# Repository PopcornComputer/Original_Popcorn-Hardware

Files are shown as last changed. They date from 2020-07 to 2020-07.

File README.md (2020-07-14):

# Original Popcorn Computer Hardware Design Files

### Important Note:
These files were put into production on July 14th, 2020 and are untested.
An upcoming production run will validate these files. This README file and repository will be updated to reflect the test results and suitability for future productions.
If results of our testing prove successful, the Original Popcorn produced from these files will be shipped to customers.

Original Popcorn Computer is designed using OrCAD 17. 
A free "lite" viewer is available at <a href="http://www.orcad.com/">www.orcad.com</a>

## License
<br />This work is licensed under a <a rel="license" href="http://creativecommons.org/licenses/by-sa/3.0/us/">Creative Commons Attribution-ShareAlike 3.0 United States License</a>.

Original Popcorn Computer is a derivative of C.H.I.P. by Next Thing Co. released under CC BY-SA 3.0.

Popcorn Computer is not affiliated with Next Thing Co.

Popcorn Computer is a trademark of Source Parts Inc.

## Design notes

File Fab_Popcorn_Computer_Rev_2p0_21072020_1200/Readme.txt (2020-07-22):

Board name	: POPCORN COMPUTER
Rev		: 2

Board Technology information:

No. of Layers		- EIGHT(8)

Board Size 		- 41mm x 60.5mm

Track/Spacing		- 4mil track and 4mil spacing

Via			- 16mil pad and 8mil drill
               
Component		- Mixed Technology

Gerber Format		- RS274-X

=================================================================

Note :

Please refer fab.art for stackup details.

Please confirm IPC netlist verification.

=================================================================

List of files in GERBER / arttoplotting

TOP.art		-> Gerber, Top side artwork
GND1.art	-> Gerber, Inner layer2 artwork
IN1.art		-> Gerber, Inner layer3 artwork
VCC1.art	-> Gerber, Inner layer4 artwork
GND2.art	-> Gerber, Inner layer5 artwork
IN2.art		-> Gerber, Inner layer6 artwork
VCC2.art	-> Gerber, Inner layer7 artwork
BOTTOM.art	-> Gerber, Bot side artwork
MASK_TOP.art	-> Gerber, Top side Solder Mask
MASK_BOT.art	-> Gerber, Bot side Solder Mask
SILK_TOP.art	-> Gerber, Top side Silkscreen
SILK_BOT.art	-> Gerber, Bot side Silkscreen

List of files in DRILL/ NC Drill

nc_tools_auto.txt		-> NC drill tool bit information
Popcorn Computer Rev 2p0_Release-1-8.drl	-> NC Drill file in excellon format
fab.art		   		-> Gerber, Fab drawing

Popcorn Computer Rev 2p0_Release.pdf -> File for visual compliance

Popcorn Computer Rev 2p0_Release.IPC -> IPC-D-356 netlist

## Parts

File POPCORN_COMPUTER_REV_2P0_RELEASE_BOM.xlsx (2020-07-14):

Popcorn Computer Rev. 2.0 Revised: Monday, July 13, 2020
Revision: 2.0
Copyright: Source Parts Inc.
Bill Of Materials July 14,2020 13:23:38 | Page1
Item | Quantity | Reference | Part | Package
______________________________________________
1 | 1 | ANT1 | NC-ANT | WIFI-ANT-SD73412-011H1_3A
2 | 1 | ANT2 | ANT | WIFI-1206
3 | 2 | C1,C5 | 18pF-1% | C0201
4 | 21 | C2,C7,C8,C13,C14,C16,C17,C18,C19,C21,C32,C45,C85,C149,C157,C167,C177,C178,C16043,C16060,C16062 | 10uF | C0603
5 | 3 | C3,C532,C533 | 0.1uF | C0603
6 | 4 | C4,C16052,C16053,C16054 | 220pF | C0603
7 | 24 | C9,C22,C24,C26,C37,C49,C150,C153,C154,C158,C159,C160,C161,C164,C179,C180,C181,C182,C183,C184,C185,C186,C296,C299 | 1uF | C0402
8 | 14 | C10,C11,C12,C25,C27,C28,C29,C50,C66,C68,C70,C71,C74,C76 | 4.7uF | C0603
9 | 1 | C15 | 102 | C0402
10 | 6 | C20,C165,C173,C174,C175,C176 | 102 | C0201
11 | 34 | C33,C34,C35,C36,C54,C69,C72,C81,C82,C83,C84,C90,C91,C92,C93,C94,C95,C96,C102,C103,C104,C105,C106,C148,C151,C152,C166,C168,C170,C172,C189,C295,C297,C298 | 104 | C0201
12 | 1 | C41 | 0.1uF | C0201
13 | 7 | C47,R50,C52,C60,C109,C530,C531 | NC | C0201
14 | 1 | C51 | 1.0pF | C0201
15 | 1 | C53 | 22pF | C0201
16 | 1 | C55 | 271 | C0201
17 | 1 | C56 | 331 | C0201
18 | 2 | C67,C73 | 47pF | C0201
19 | 9 | C78,C79,C527,C528,C16037,C16041,C16042,C16055,C16056 | 22uF | C0805
20 | 2 | C142,C169 | 4.7uF | C0402
21 | 1 | C188 | 4.7u/6.3V | C0603
22 | 4 | C220,C221,C223,C224 | 104 | C0402
23 | 1 | C222 | NC/104 | C0402
24 | 1 | C294 | 100pF | C0201
25 | 6 | C496,C497,C498,C499,C510,C514 | 0.1uF/10V | C0402
26 | 2 | C512,C513 | 4.7uF/10V | C0603
27 | 5 | C524,C526,C16071,C16072,C16073 | 0.1uf | C0402
28 | 1 | C525 | 10uf | C0805
29 | 1 | C529 | 75Pf | C0402
30 | 1 | C16038 | 100uF / 10V | C1210
31 | 1 | C16039 | 1uf | C0201
32 | 1 | C16040 | 22uF/10V | C0805
33 | 2 | C16057,C16058 | 1uF | C0603
34 | 2 | C16059,C16061 | 0.1uF/50V | C0603
35 | 4 | C16067,C16068,C16069,C16070 | 10NF/35V | C0402
36 | 1 | D1 | PWR | D0603
37 | 1 | D2 | STAT | D0603
38 | 1 | D18 | BAT54S | SOT-23
39 | 1 | D21 | LED | D0603
40 | 1 | ESD38 | NC/AU0511P1 | R0402
41 | 2 | J2,J1202 | USB Type-C | DX07B024JJ1R1500
42 | 1 | J3 | BATTERY | CON2-PT2-6X6H4_7B
43 | 1 | J4 | HEADER 2 | hdr_2x1
44 | 1 | J1204 | USB-MACRO-SOCKET | usb-mic-a01sb141bh2_4a
45 | 5 | L2,L3,L4,L5,L6 | 2.2uH-DCR<0.1R-1.5A/ELL4LG2R2NA | L3518
46 | 1 | L9 | 1.8uH | L0603
47 | 1 | L10 | 12UH | ASPI-6045S-120M-T
48 | 1 | L9003 | SLW4012P1R5MST | SLW4012P1R5MST
49 | 1 | L9004 | 180nH | L0603
50 | 1 | Q4 | MMBT3904 | SOT-23
51 | 1 | Q11 | BSN20 | SOT-23
52 | 10 | RN20,RN21,RN22,RN23,RN24,RN25,RN26,RN27,RN28,RN29 | 33R*4 | YC124-FR-0724RL
53 | 1 | RN30 | 24R*4 | YC124-FR-0724RL
54 | 2 | RN31,RN32 | 10k | YC124-JR-0710KL
55 | 2 | R1,R4 | 4.7K | C0201
56 | 5 | R2,R3,R6,R18,R103 | 2K2 | C0201
57 | 1 | R7 | 0R03 | R0805
58 | 4 | R8,R83,R102,R113 | 1K | C0201
59 | 1 | R9 | 1R | R0402
60 | 5 | R10,R11,R55,R56,R206 | 10K | C0201
61 | 2 | R12,R122 | 0R | C0201
62 | 2 | R13,R121 | 200K-1% | C0201
63 | 2 | R14,R78 | 100K-1% | C0201
64 | 1 | R15 | 150K-1% | C0201
65 | 2 | R16,R17 | 47K | C0201
66 | 1 | R20 | 2K | C0201
67 | 1 | R45 | 1.2pF | C0201
68 | 5 | R48,R49,R51,R52,R53 | 33K | C0201
69 | 2 | R58,R59 | NC-10K | C0201
70 | 1 | R60 | 75R | C0201
71 | 1 | R61 | NC-0R | C0201
72 | 2 | R62,R63 | NC/0R | C0201
73 | 6 | R65,R66,R105,R909,R1001,R1002 | 100K | C0201
74 | 6 | R68,R100,R101,R420,R421,R422 | 24R | C0201
75 | 2 | R71,R94 | 240R-1% | C0201
76 | 1 | R77 | 0 | C0201
77 | 1 | R79 | 442K-1% | C0201
78 | 1 | R80 | NC-0R | R0805
79 | 1 | R81 | 0R | R0805
80 | 4 | R89,R90,R91,R416 | 2K-1% | C0201
81 | 1 | R192 | 1.5K | C0201
82 | 1 | R209 | NC/10K | R0402
83 | 1 | R888 | 22R/1% | R0402
84 | 1 | R890 | 10K | R0402
85 | 1 | R908 | 49.9 | C0201
86 | 1 | R910 | 13.3K | C0201
87 | 1 | R1000 | 470ohm | C0201
88 | 2 | R16038,R16077 | 1MOHM | R0402
89 | 1 | R16039 | 315.8kOHM | R0402
90 | 14 | R16053,R16054,R16055,R16056,R16060,R16061,R16062,R16063,R16069,R16070,R16071,R16072,R16075,R16076 | 10.0k | R0201
91 | 3 | R16057,R16058,R16074 | 100K | R0402
92 | 1 | R16064 | 23.7K | R0402
93 | 2 | R16065,R16067 | 5K | R0402
94 | 1 | R16066 | 13.7K | R0402
95 | 1 | R16068 | 51.1K | R0402
96 | 1 | R16073 | 510K | R0402
97 | 1 | R16078 | NC/0R | R0603
98 | 1 | SW1 | KEY-2PIN_0 | SW_4P_TC3061B
99 | 1 | SW2 | SW_PB_SPST | SW_4P_TC3061B
100 | 3 | TP2,TP13,TP14 | DC3-SET | TP30_SMD
101 | 1 | TP3 | LS | PAD5_5D3
102 | 1 | TP4 | VMIC | TP30_SMD
103 | 3 | TVS1,TVS2,TVS3 | TVS2200 | TVS2200
104 | 2 | T84,T85 | TP_0.7 | TP30_SMD
105 | 1 | U1 | R8 | TQFP177P0_4
106 | 1 | U3 | AXP209 | QFN49_0_4H0_8A
107 | 1 | U4 | LP3220SAB5F/SY8088 | SOT23_5H14A
108 | 1 | U8 | TS5USBA224RSWR | TS5USBA224
109 | 1 | U9 | 8723BS | QFN44-AP6476-12X12H1_6A
110 | 1 | U10 | TS3A226AEYFFR | TS3A226AE
111 | 1 | U12 | LP3220SAB5F\SY8088 | SOT23_5H14A
112 | 2 | U13,U14 | LCD_CN | CON2X20-PT2_54-5_2X31_2H2A
113 | 1 | U29 | DDR3-FBGA96 | FBGA96C80P9X13
114 | 1 | U34 | NCEMASD9-08G | NCEMASD9-08G
115 | 1 | U38 | TPS54302DDCR | sot23_6p
116 | 1 | U39 | RDSW282/XMSS1R6G0PA-001 | rfsw6b105_105h40
117 | 1 | U40 | CH340E | msop10
118 | 1 | U41 | WAS7227Q | WAS7227Q
119 | 1 | U42 | TPS65988 | slvsdb5a
120 | 2 | U46,U47 | TPD6S300 | QFN20
121 | 1 | U48 | W25X05CLSNIG | soic8
122 | 1 | U49 | TPS2069 | HVSSOP_8
123 | 1 | U50 | TPS2120 | TPS2120
124 | 1 | U9012 | SY7088 | SY7088
125 | 1 | X1 | 24M-20pF-10PPM | CRYSTAL-4P-3225-H1A

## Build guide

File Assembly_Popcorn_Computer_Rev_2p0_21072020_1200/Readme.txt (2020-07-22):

Board name	: POPCORN COMPUTER
Rev		: 2

Board Technology information:

No. of Layers		- EIGHT(8)

Board Size 		- 41mm x 60.5mm

Track/Spacing		- 4mil track and 4mil spacing

Via			- 16mil pad and 8mil drill
               
Component		- Mixed Technology

Gerber Format		- RS274-X

=================================================================

List of files in ASSY/ for Assembly
PASTE_TOP.art		-> Gerber, Top Side Solder Paste
PASTE_BOT.art		-> Gerber, Bot Side Solder Paste
ASSEMBLY_TOP.art	-> Gerber, Top Assembly Drawing
ASSEMBLY_BOT.art	-> Gerber, Bot Assembly Drawing
place_txt.txt		-> Components XY Location

Popcorn Computer Rev 2p0_Assembly.pdf -> File for visual compliance

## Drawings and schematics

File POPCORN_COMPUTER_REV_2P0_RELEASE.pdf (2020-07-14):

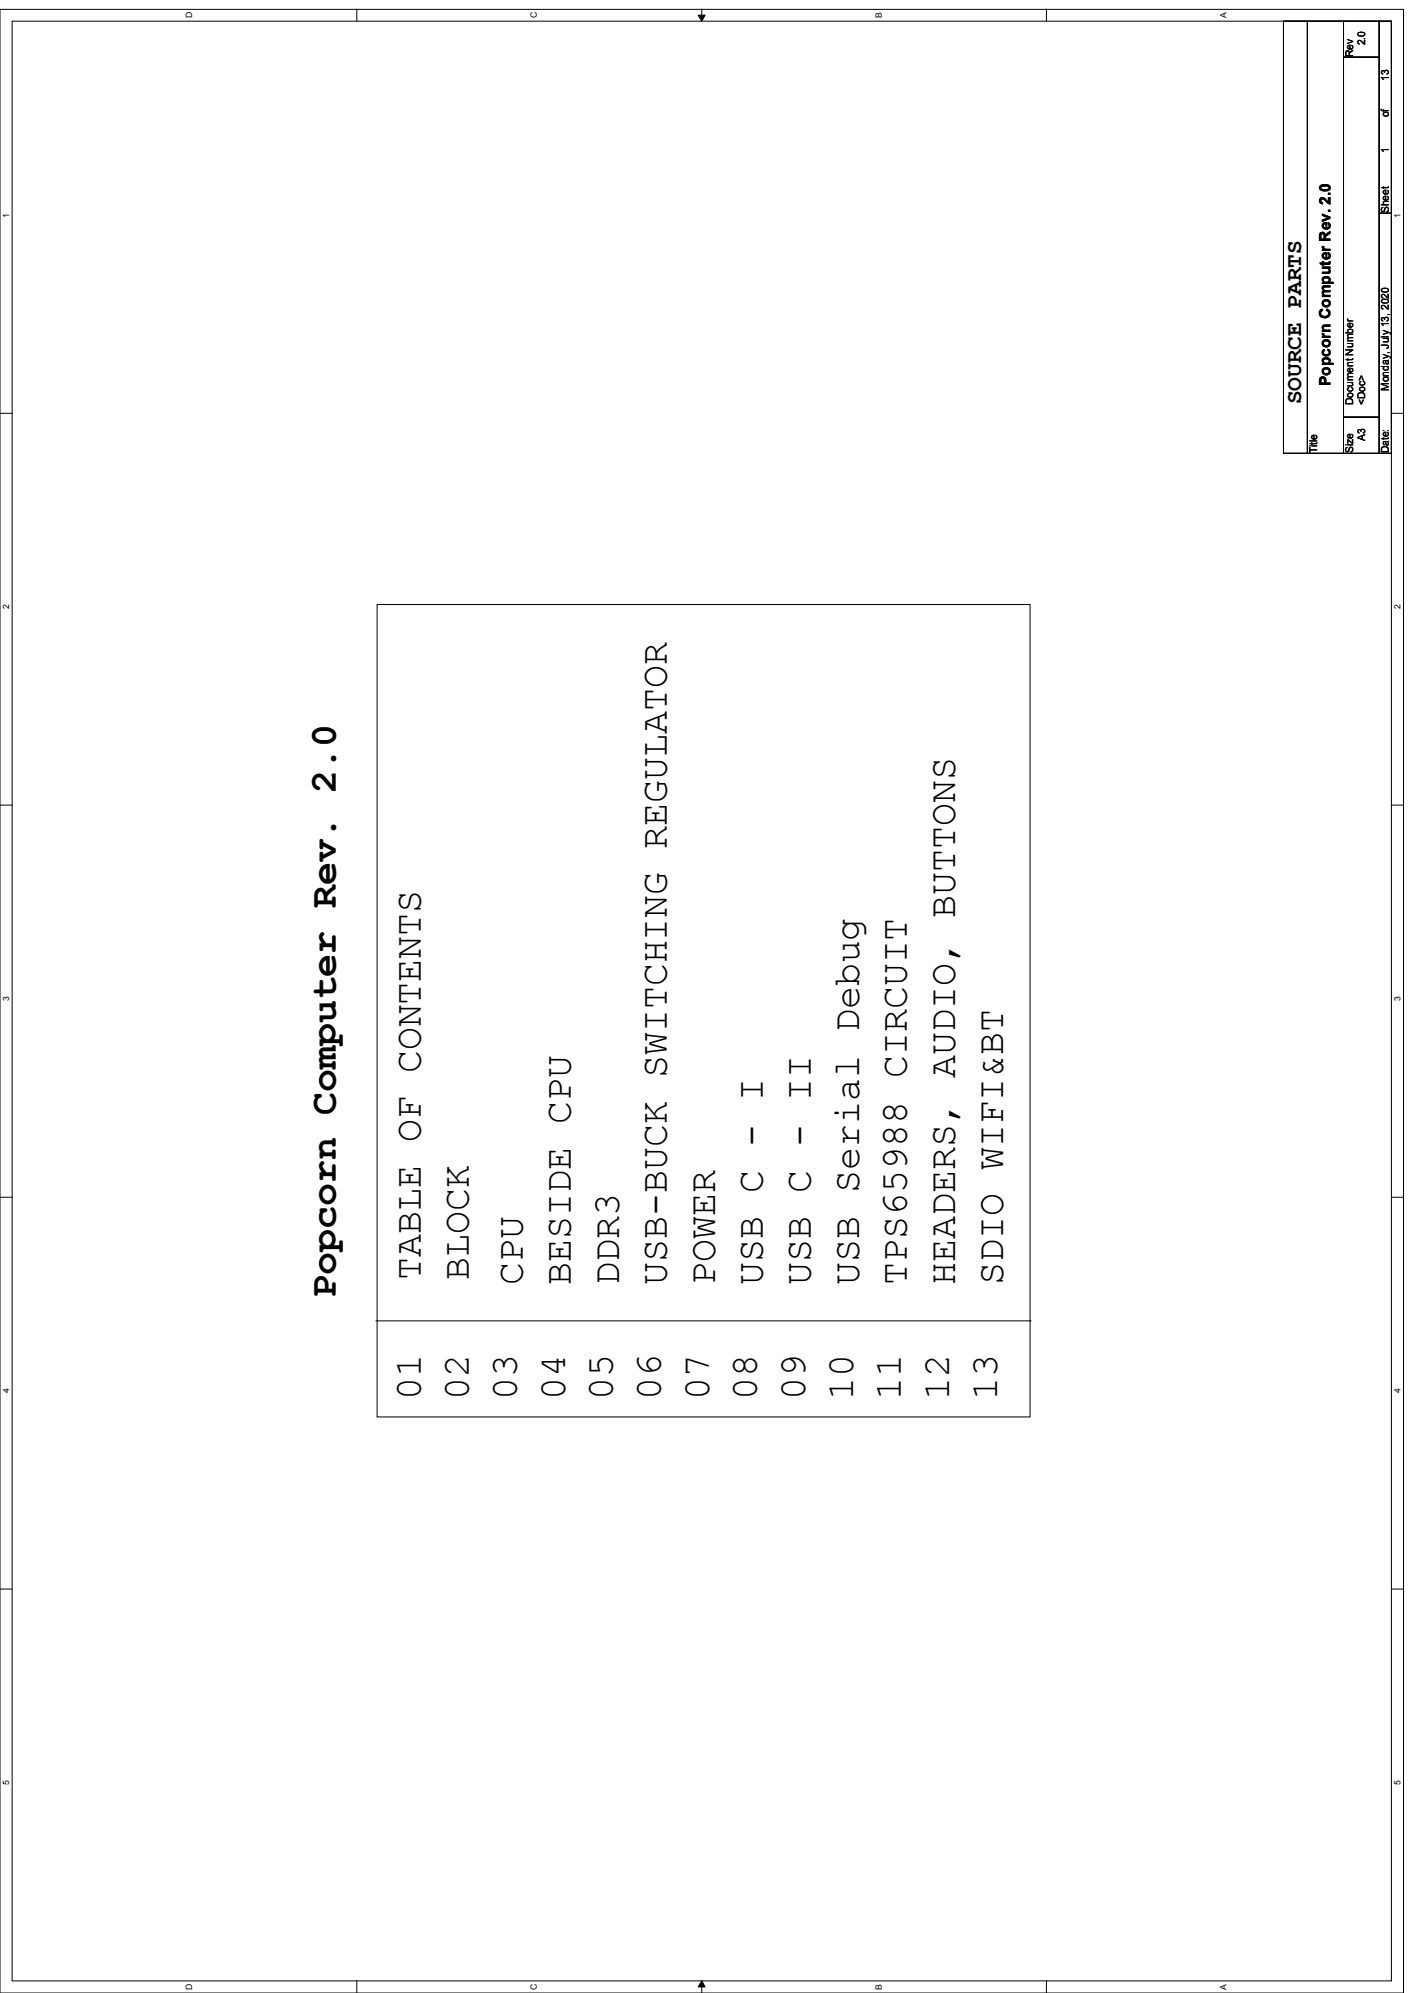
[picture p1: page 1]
SOURCE PARTS; BLOCK; CPU; BESIDE CPU; DDR3; POWER; USB C - I; USB C - II; TPS65988 CIRCUIT; Title; <Doc> 2.0; 1 13 Monday, July 13, 2020

Size Document Number Rev

Date: Sheet of

Popcorn Computer Rev. 2.0

USB-BUCK SWITCHING REGULATOR

HEADERS, AUDIO, BUTTONS

TABLE OF CONTENTS

USB Serial Debug

SDIO WIFI&BT

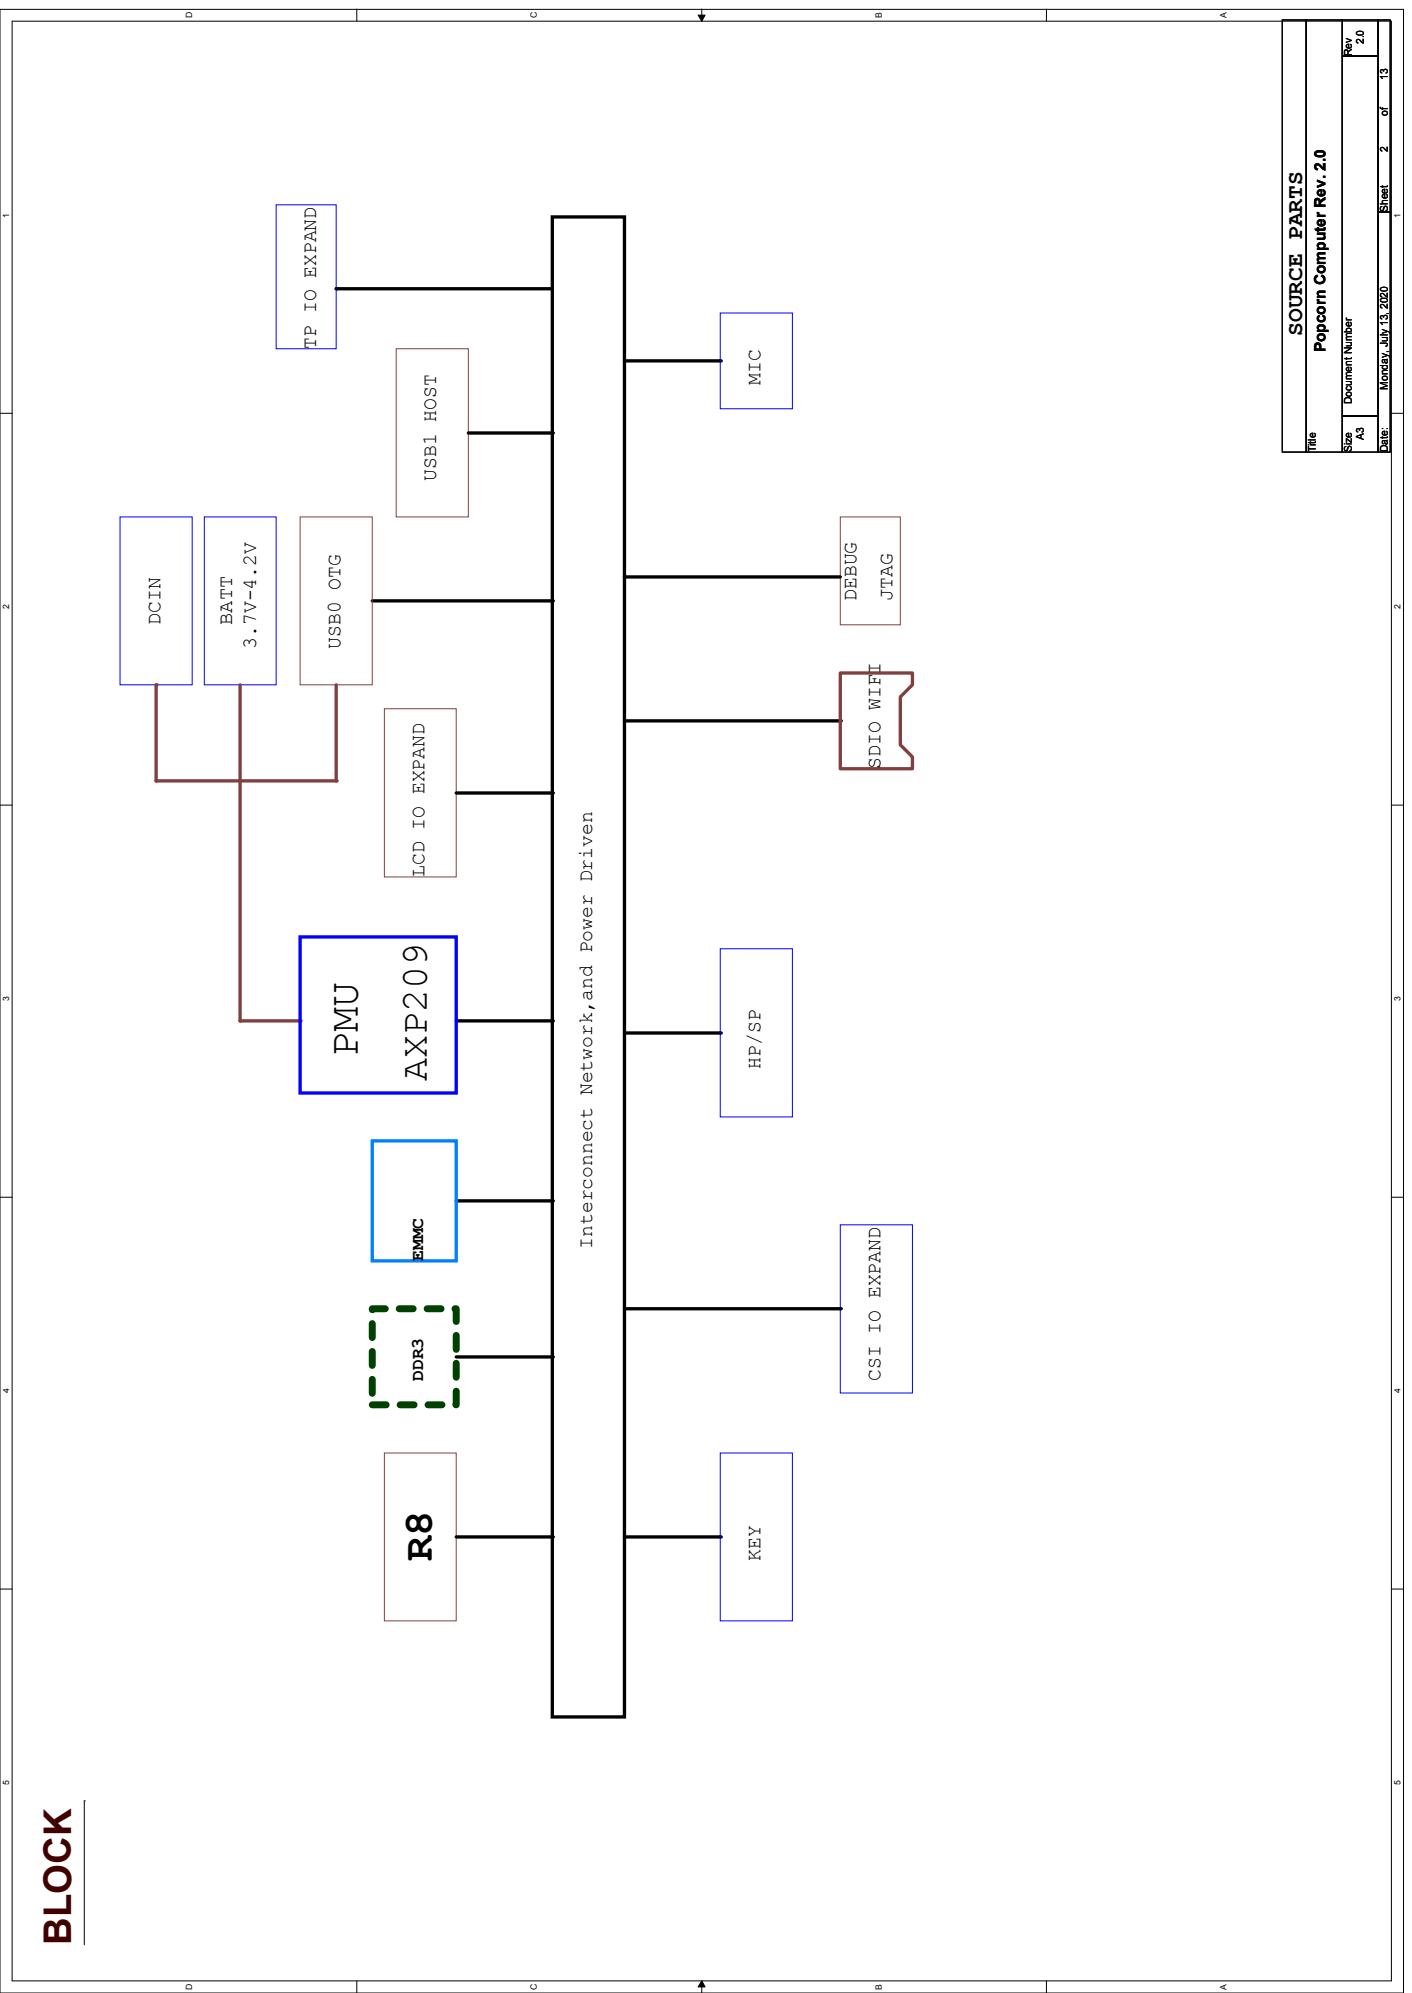
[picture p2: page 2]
SDIO WIFI; BATT; DCIN; USB0 OTG; DEBUG; JTAG; KEY; PMU; AXP209; MIC; BLOCK; EMMC; USB1 HOST; DDR3 R8; SOURCE PARTS; Title; 2 13 Monday, July 13, 2020

Size Document Number Rev

Date: Sheet of

Popcorn Computer Rev. 2.0

TP IO EXPAND

LCD IO EXPAND

Interconnect Network,and Power Driven

CSI IO EXPAND

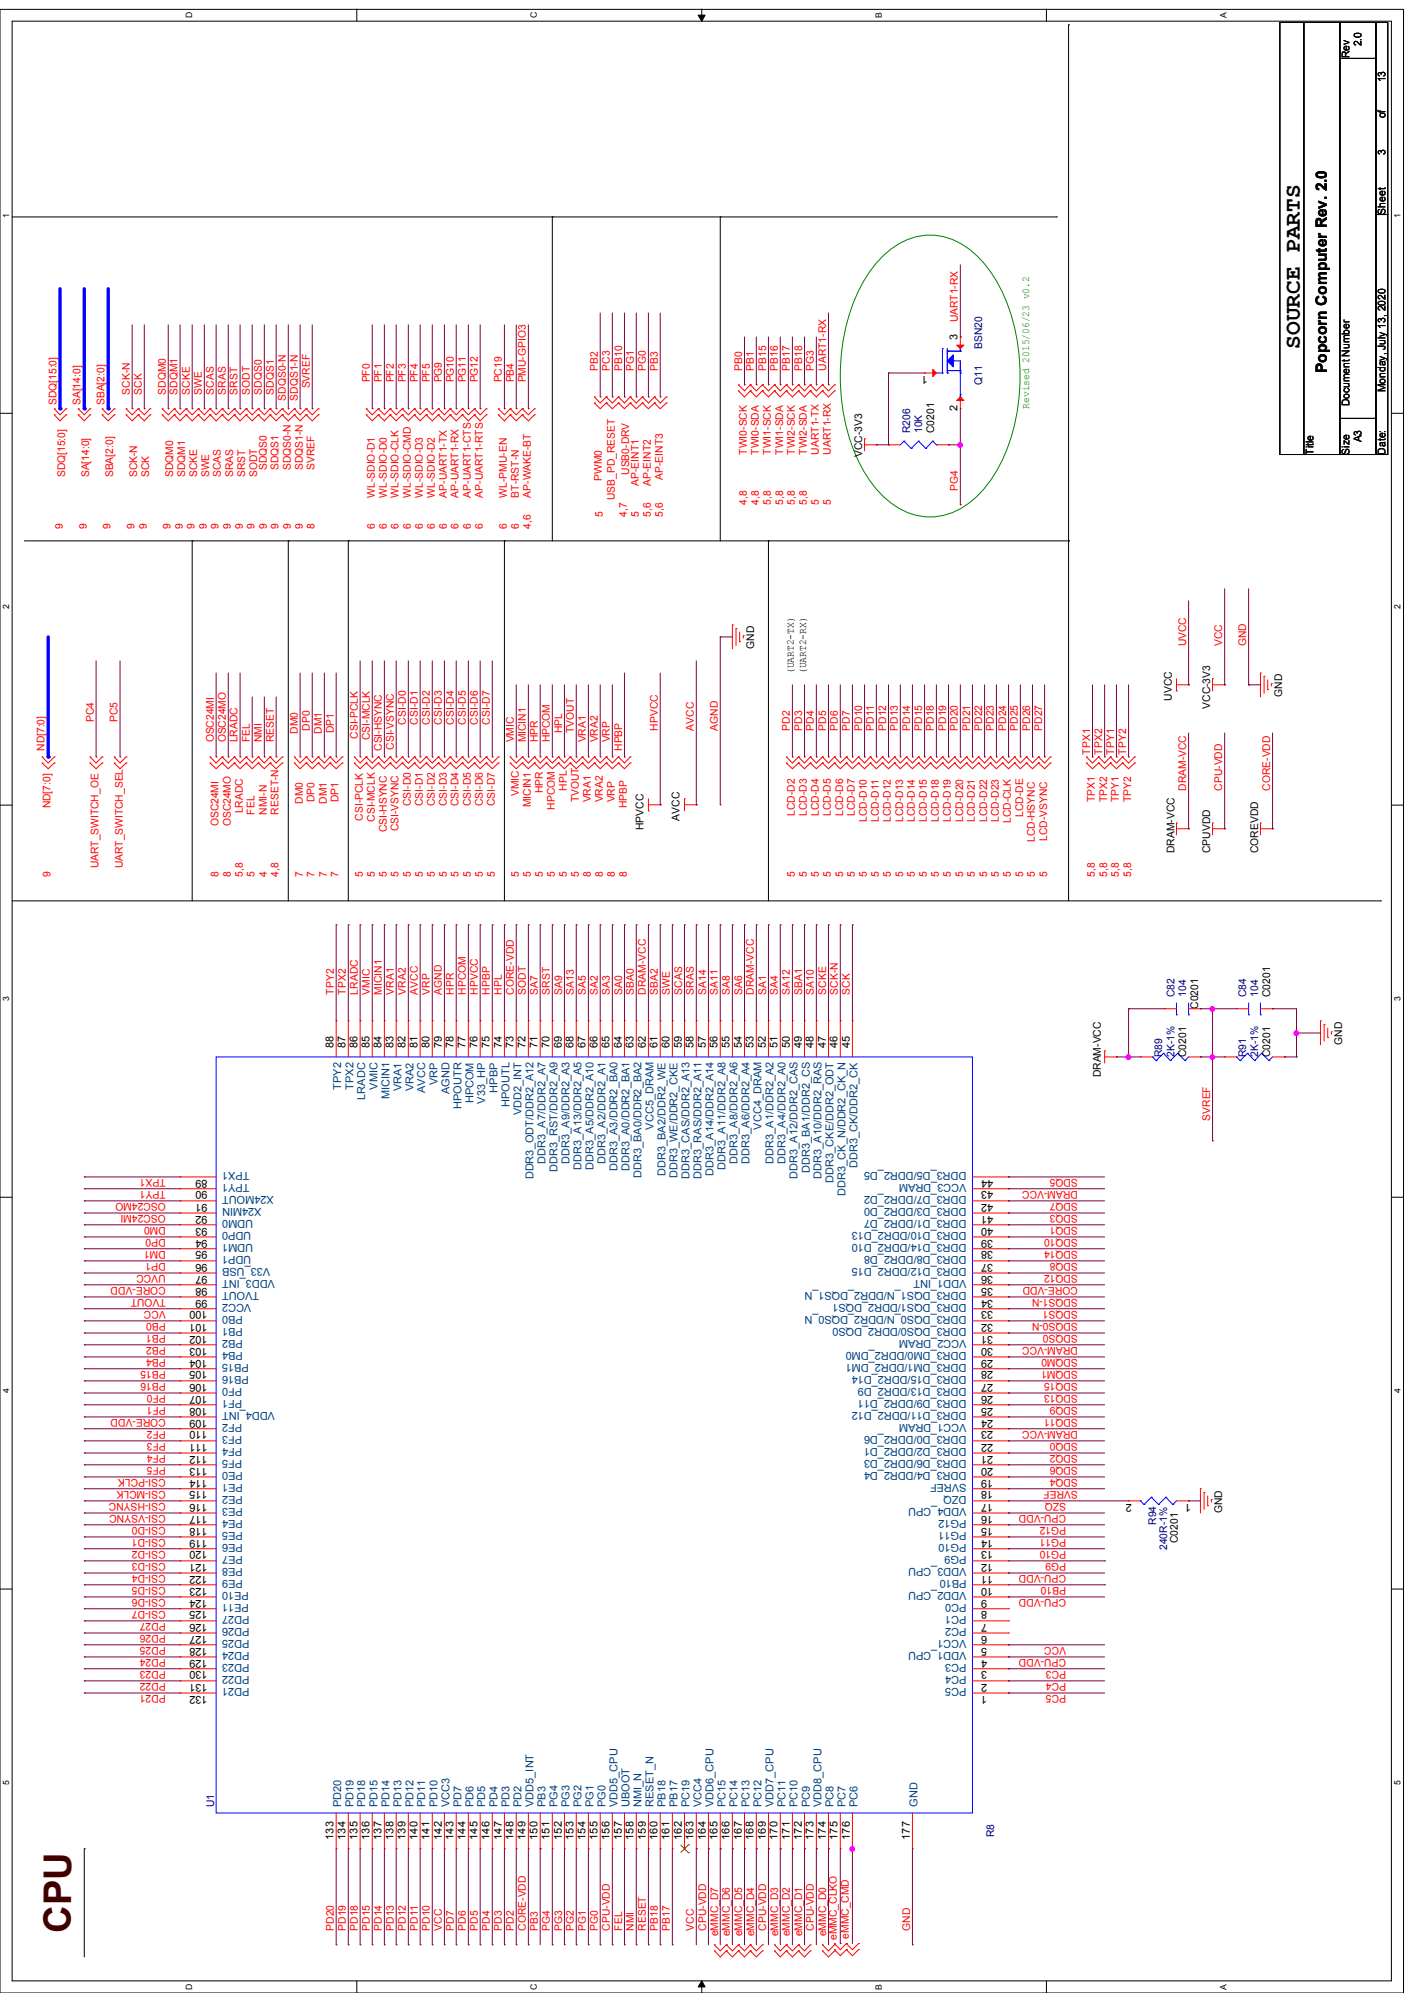
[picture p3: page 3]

Size Document Number Rev

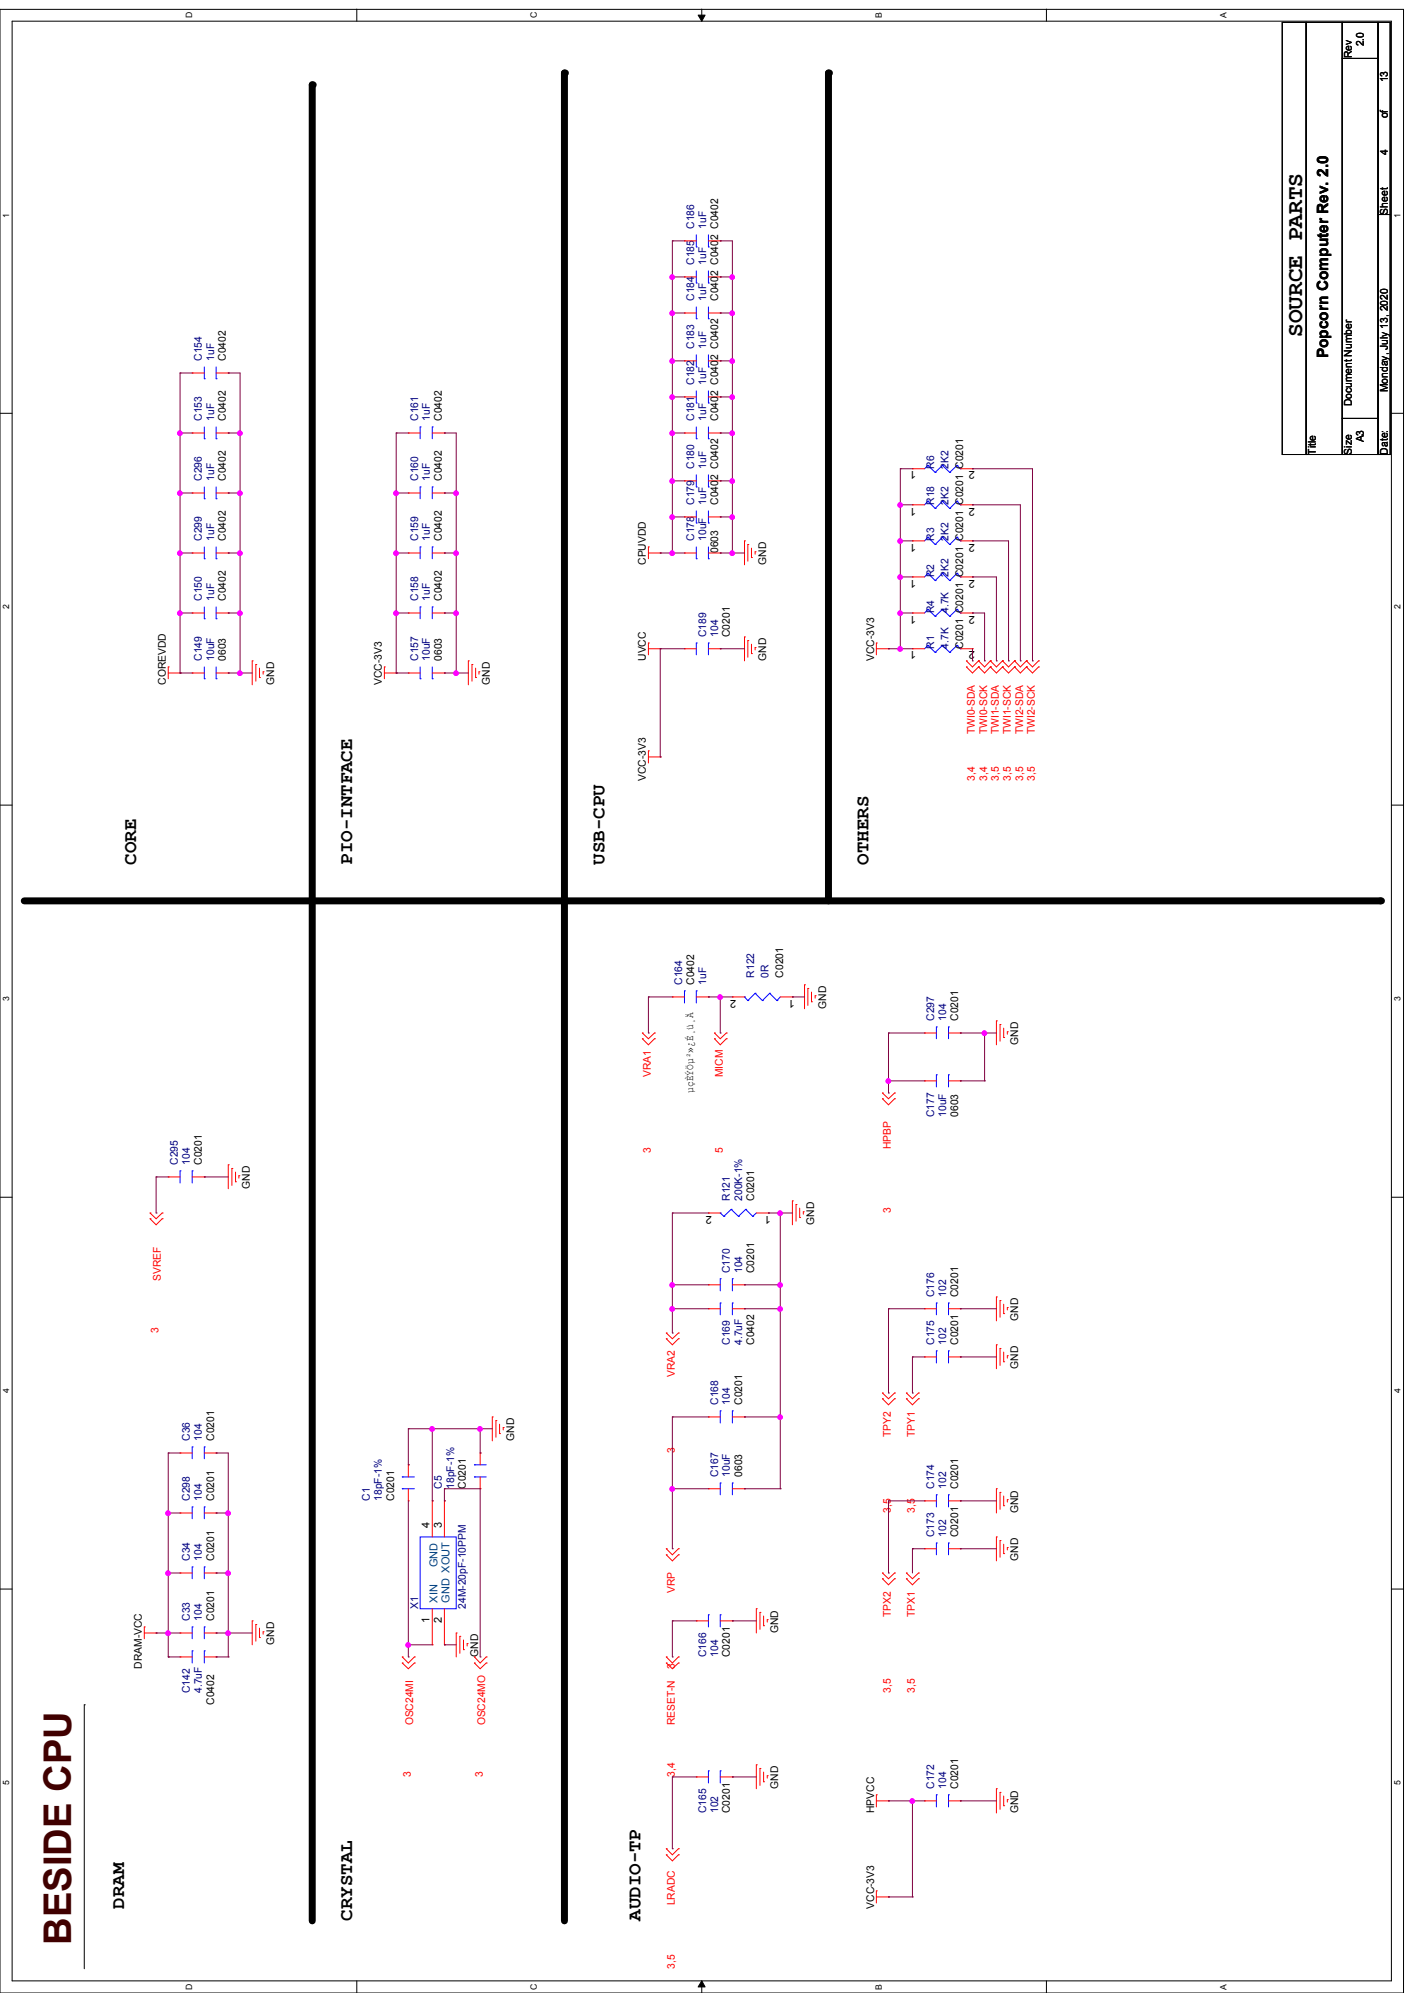
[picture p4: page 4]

Size Document Number Rev

GND GND GND

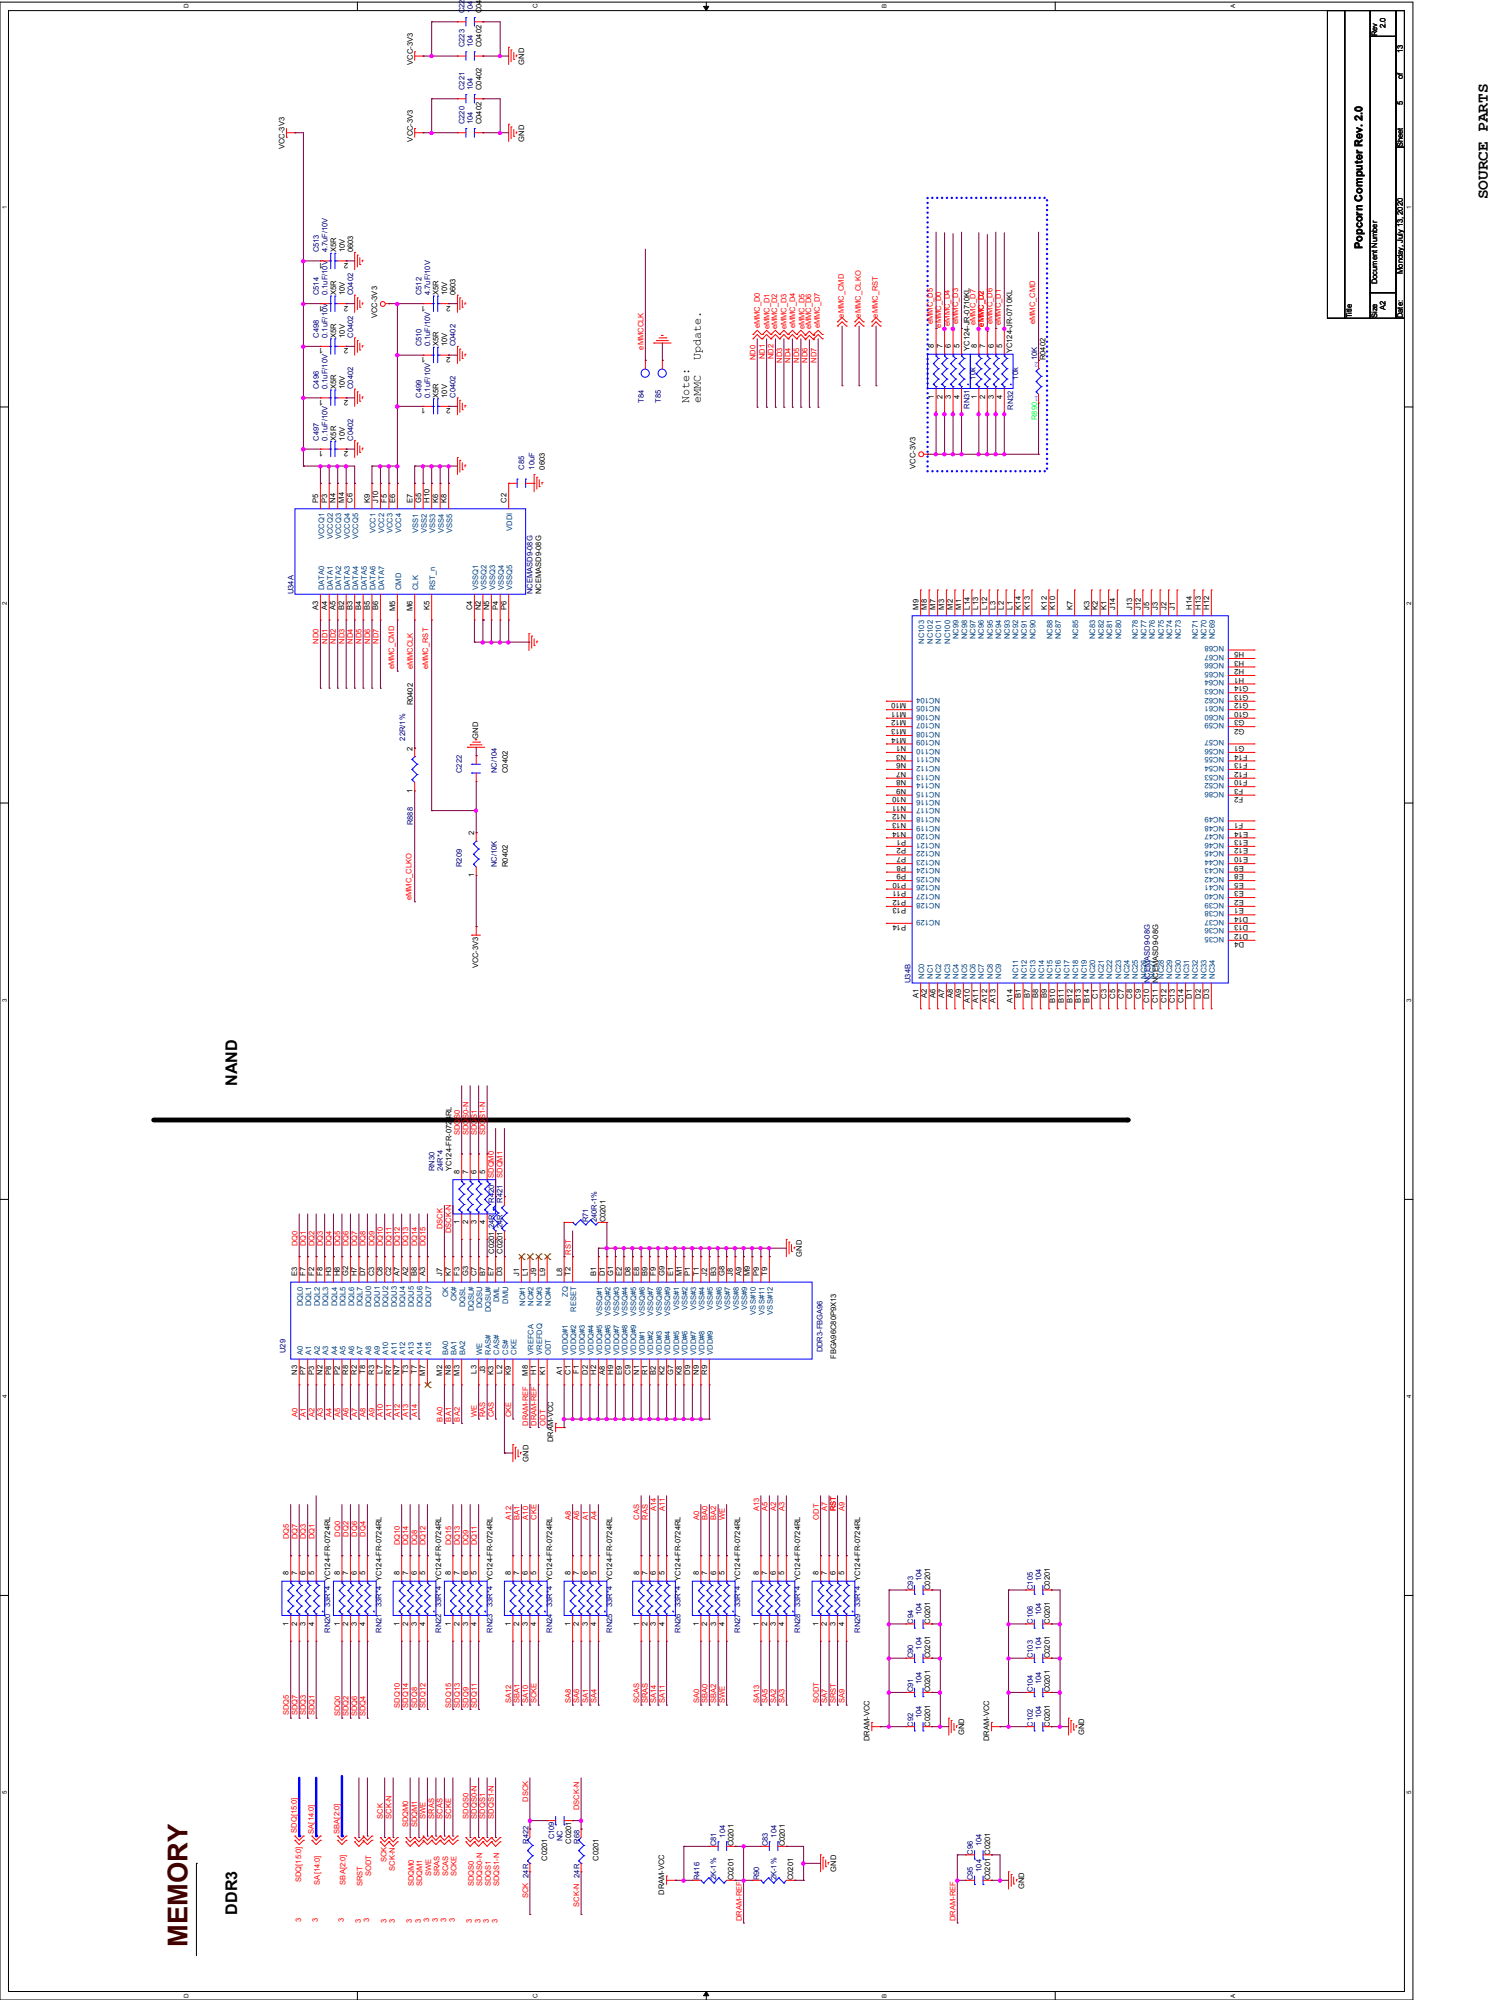
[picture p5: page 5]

Size Document Number Rev

SCAS CAS eMMCCLK SRAS RAS

SCK DSCK SA10 A10 DRAM-REF

SCKE CKE DRAM-REF

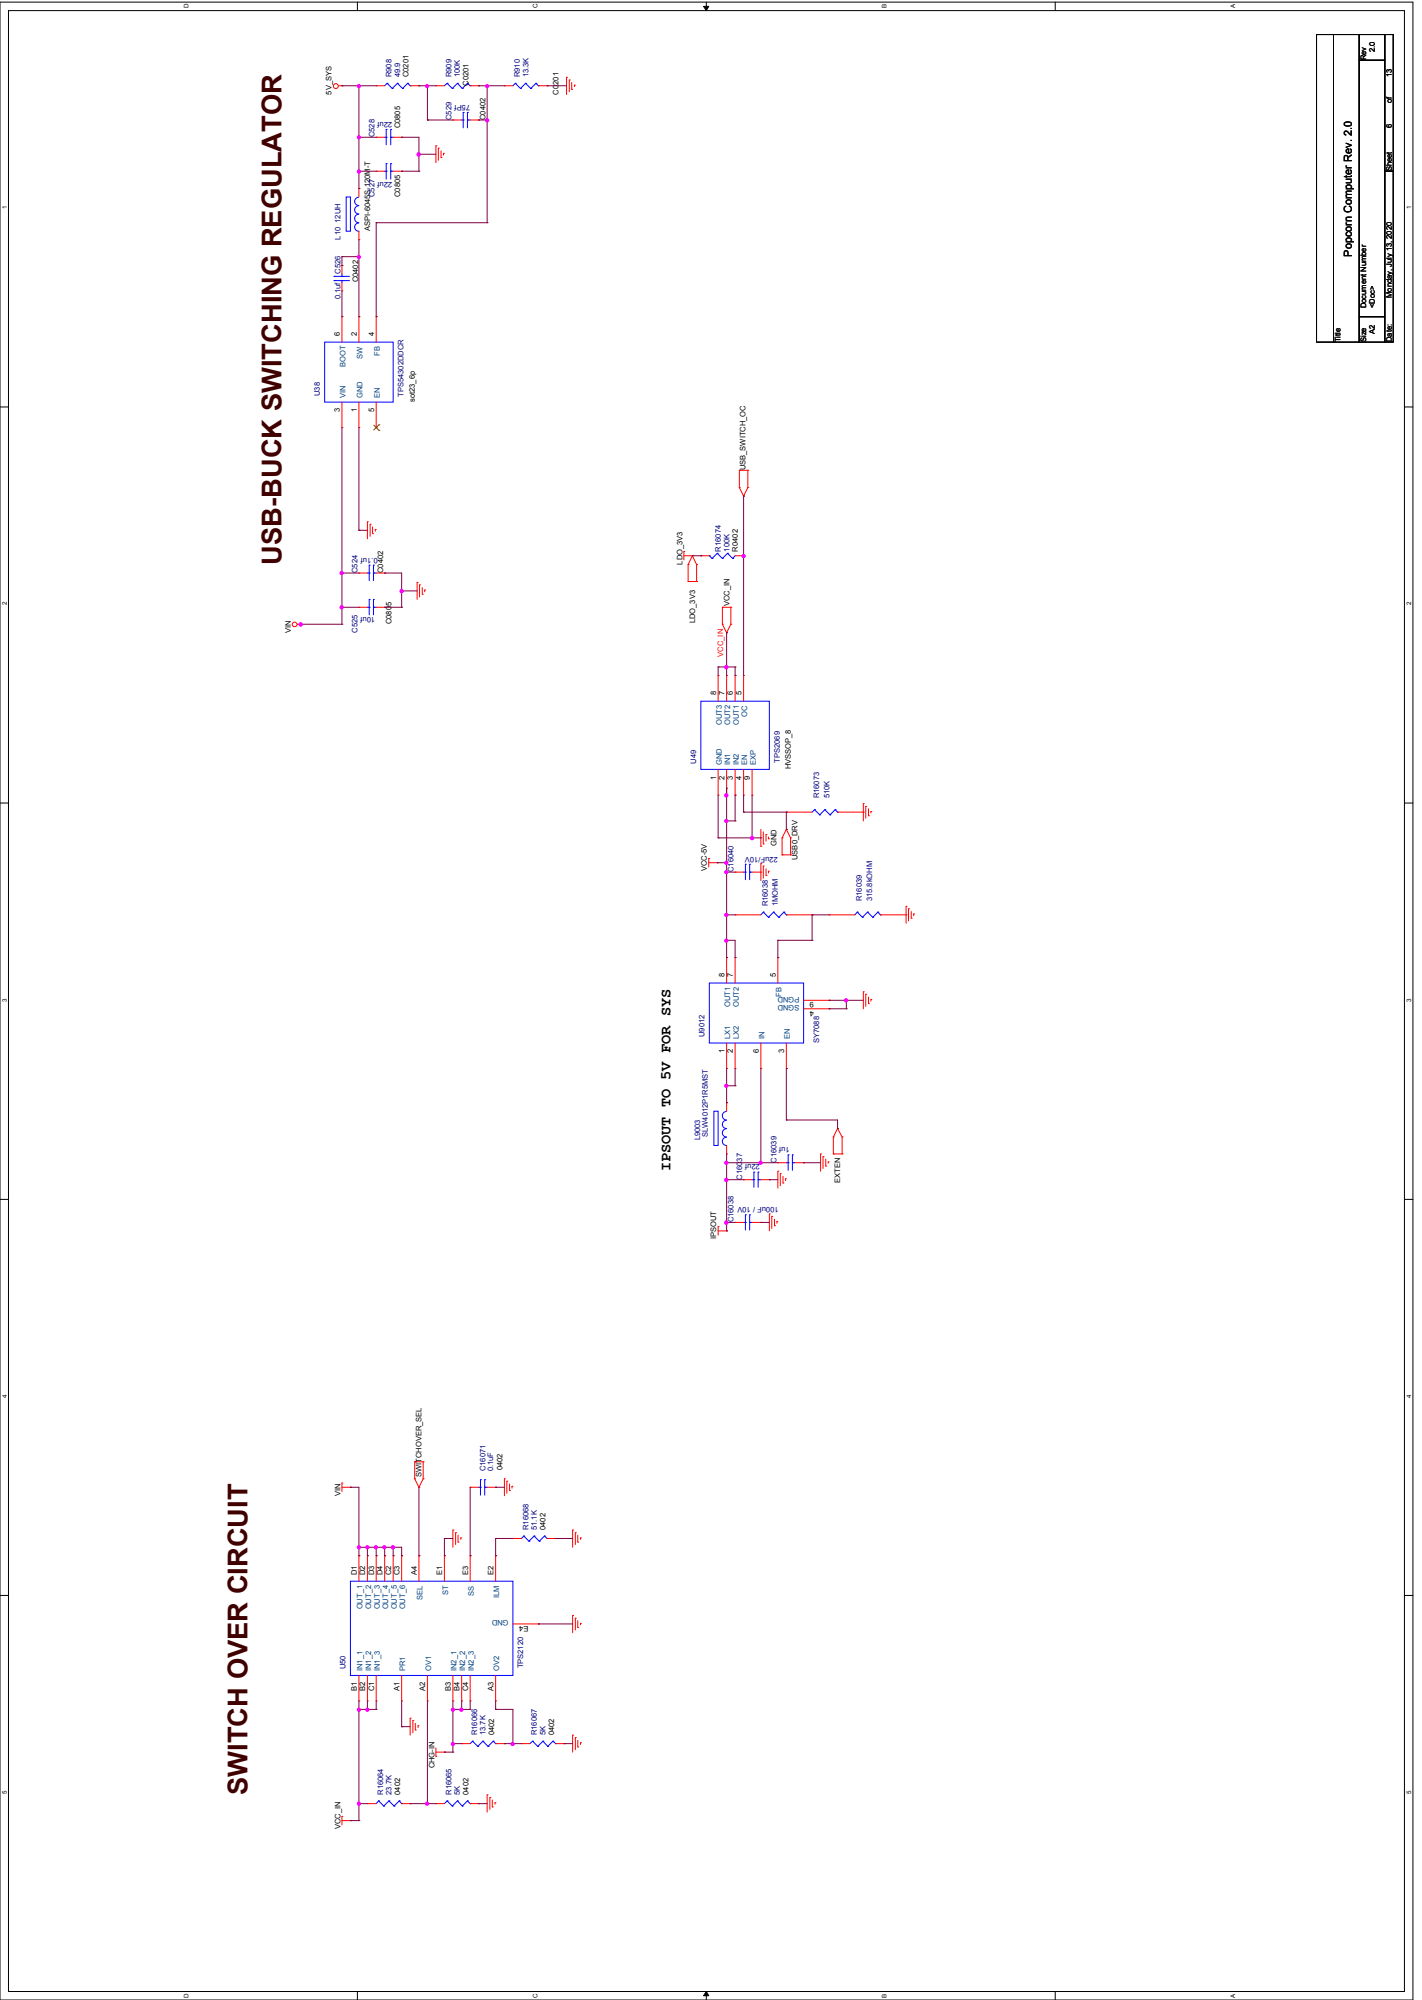
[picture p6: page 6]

Size Document Number Rev

USB-BUCK SWITCHING REGULATOR

IPSOUT TO 5V FOR SYS

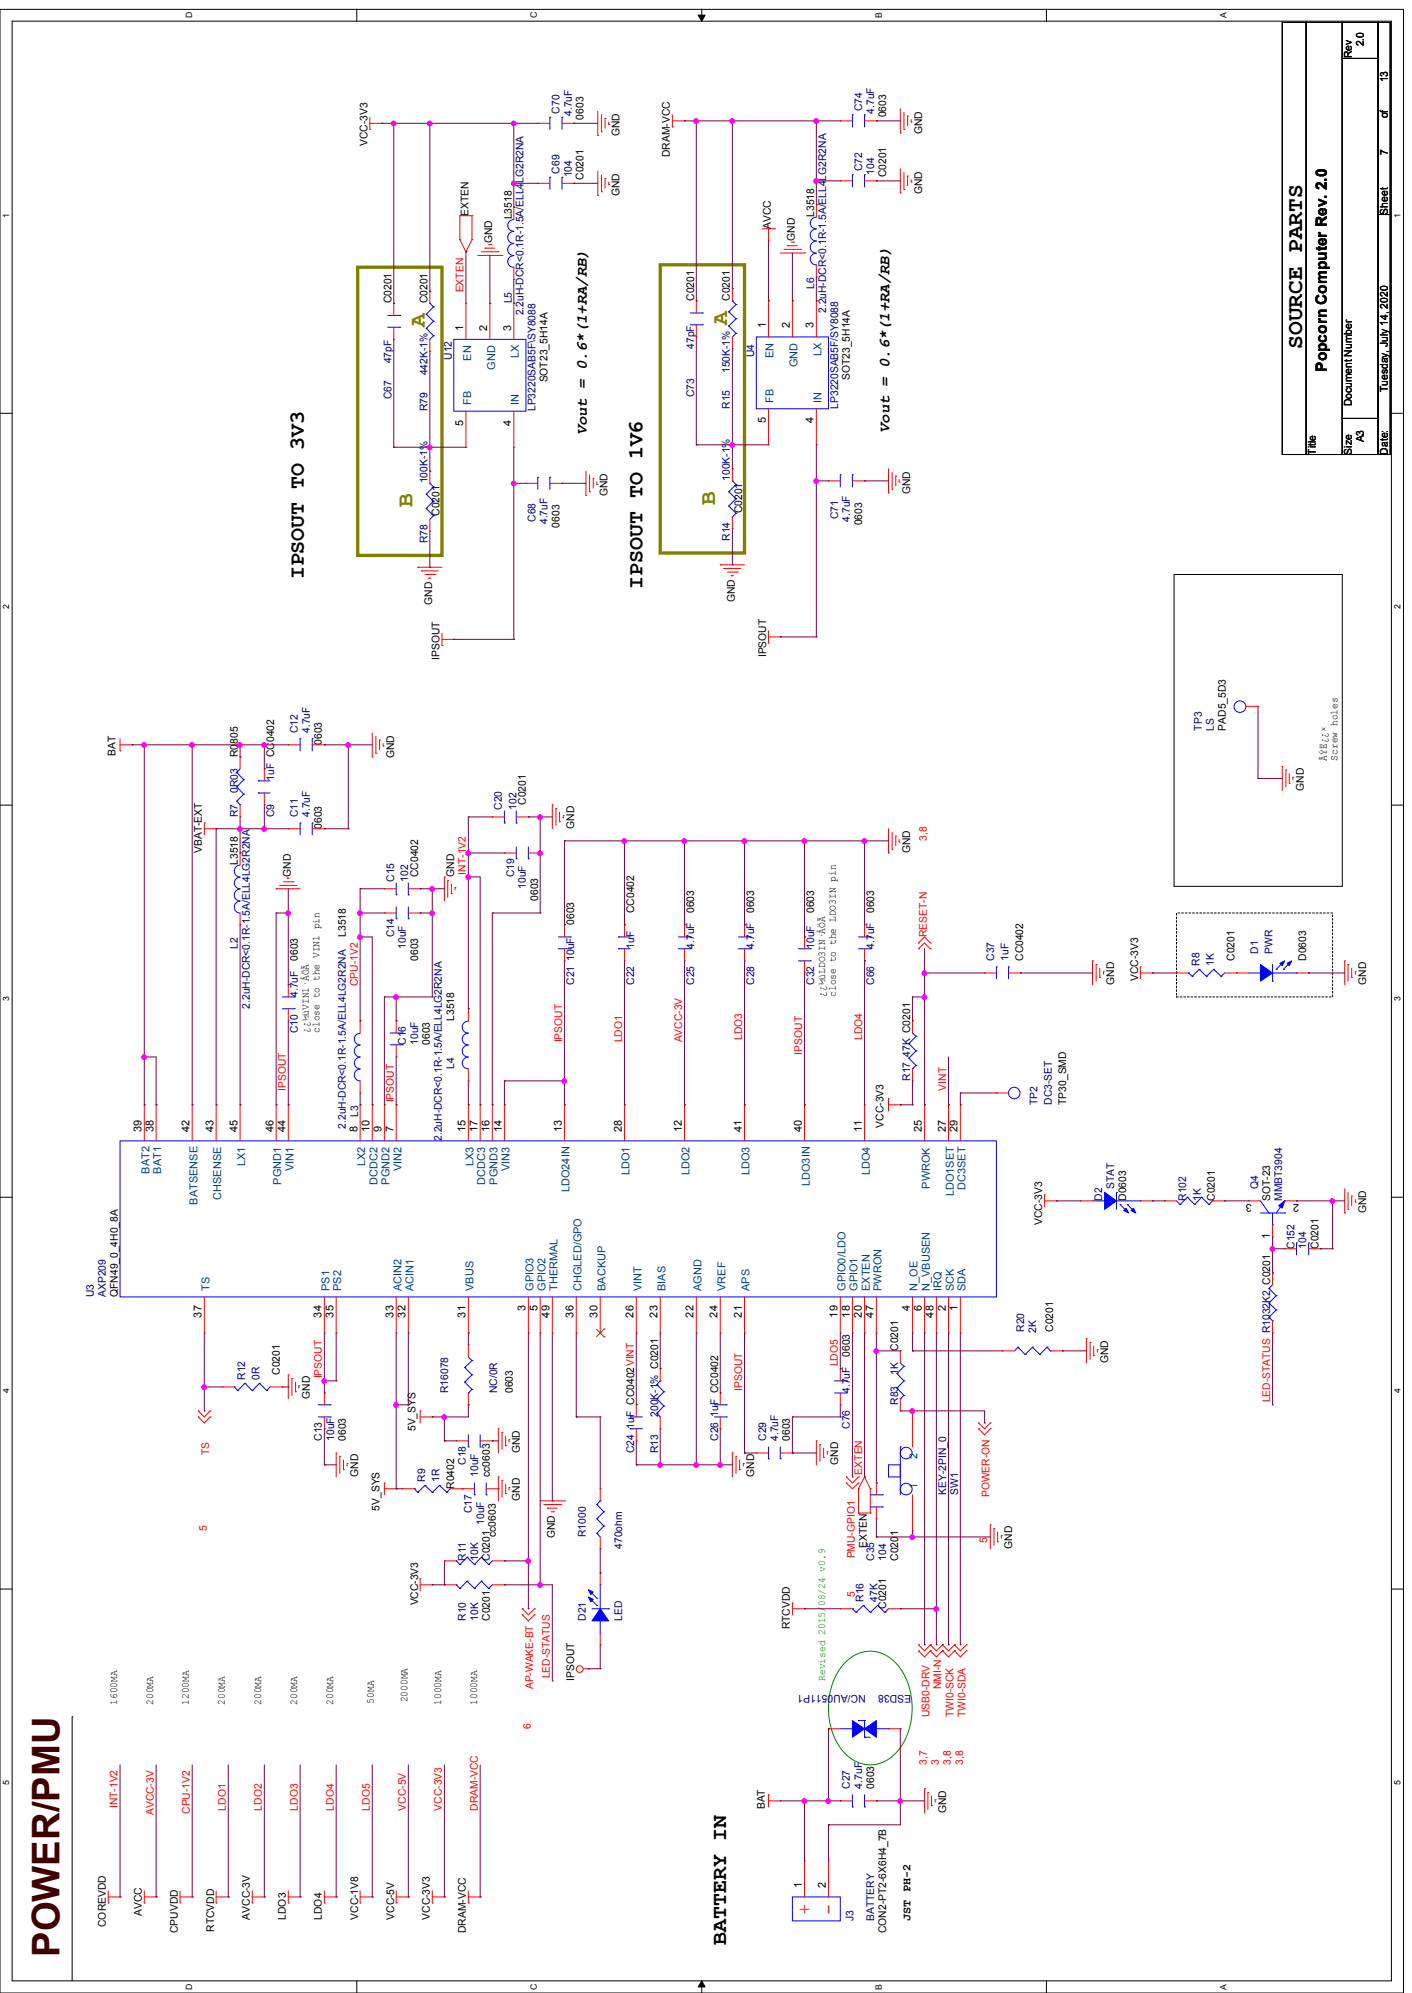
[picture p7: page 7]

Size Document Number Rev

close to the LDO3IN pin

close to the VIN1 pin

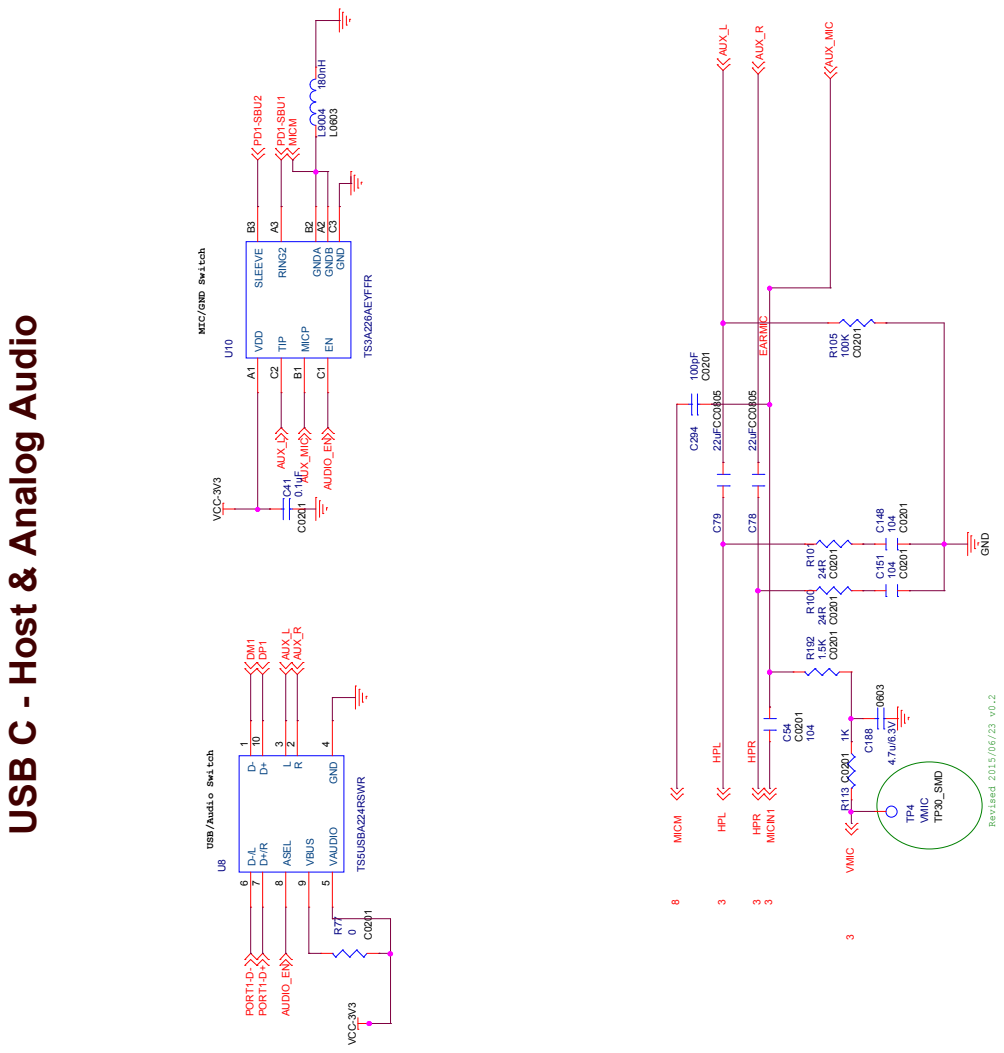
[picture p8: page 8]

Size Document Number Rev

MIC/GND Switch USB/Audio Switch

USB C - Host & Analog Audio

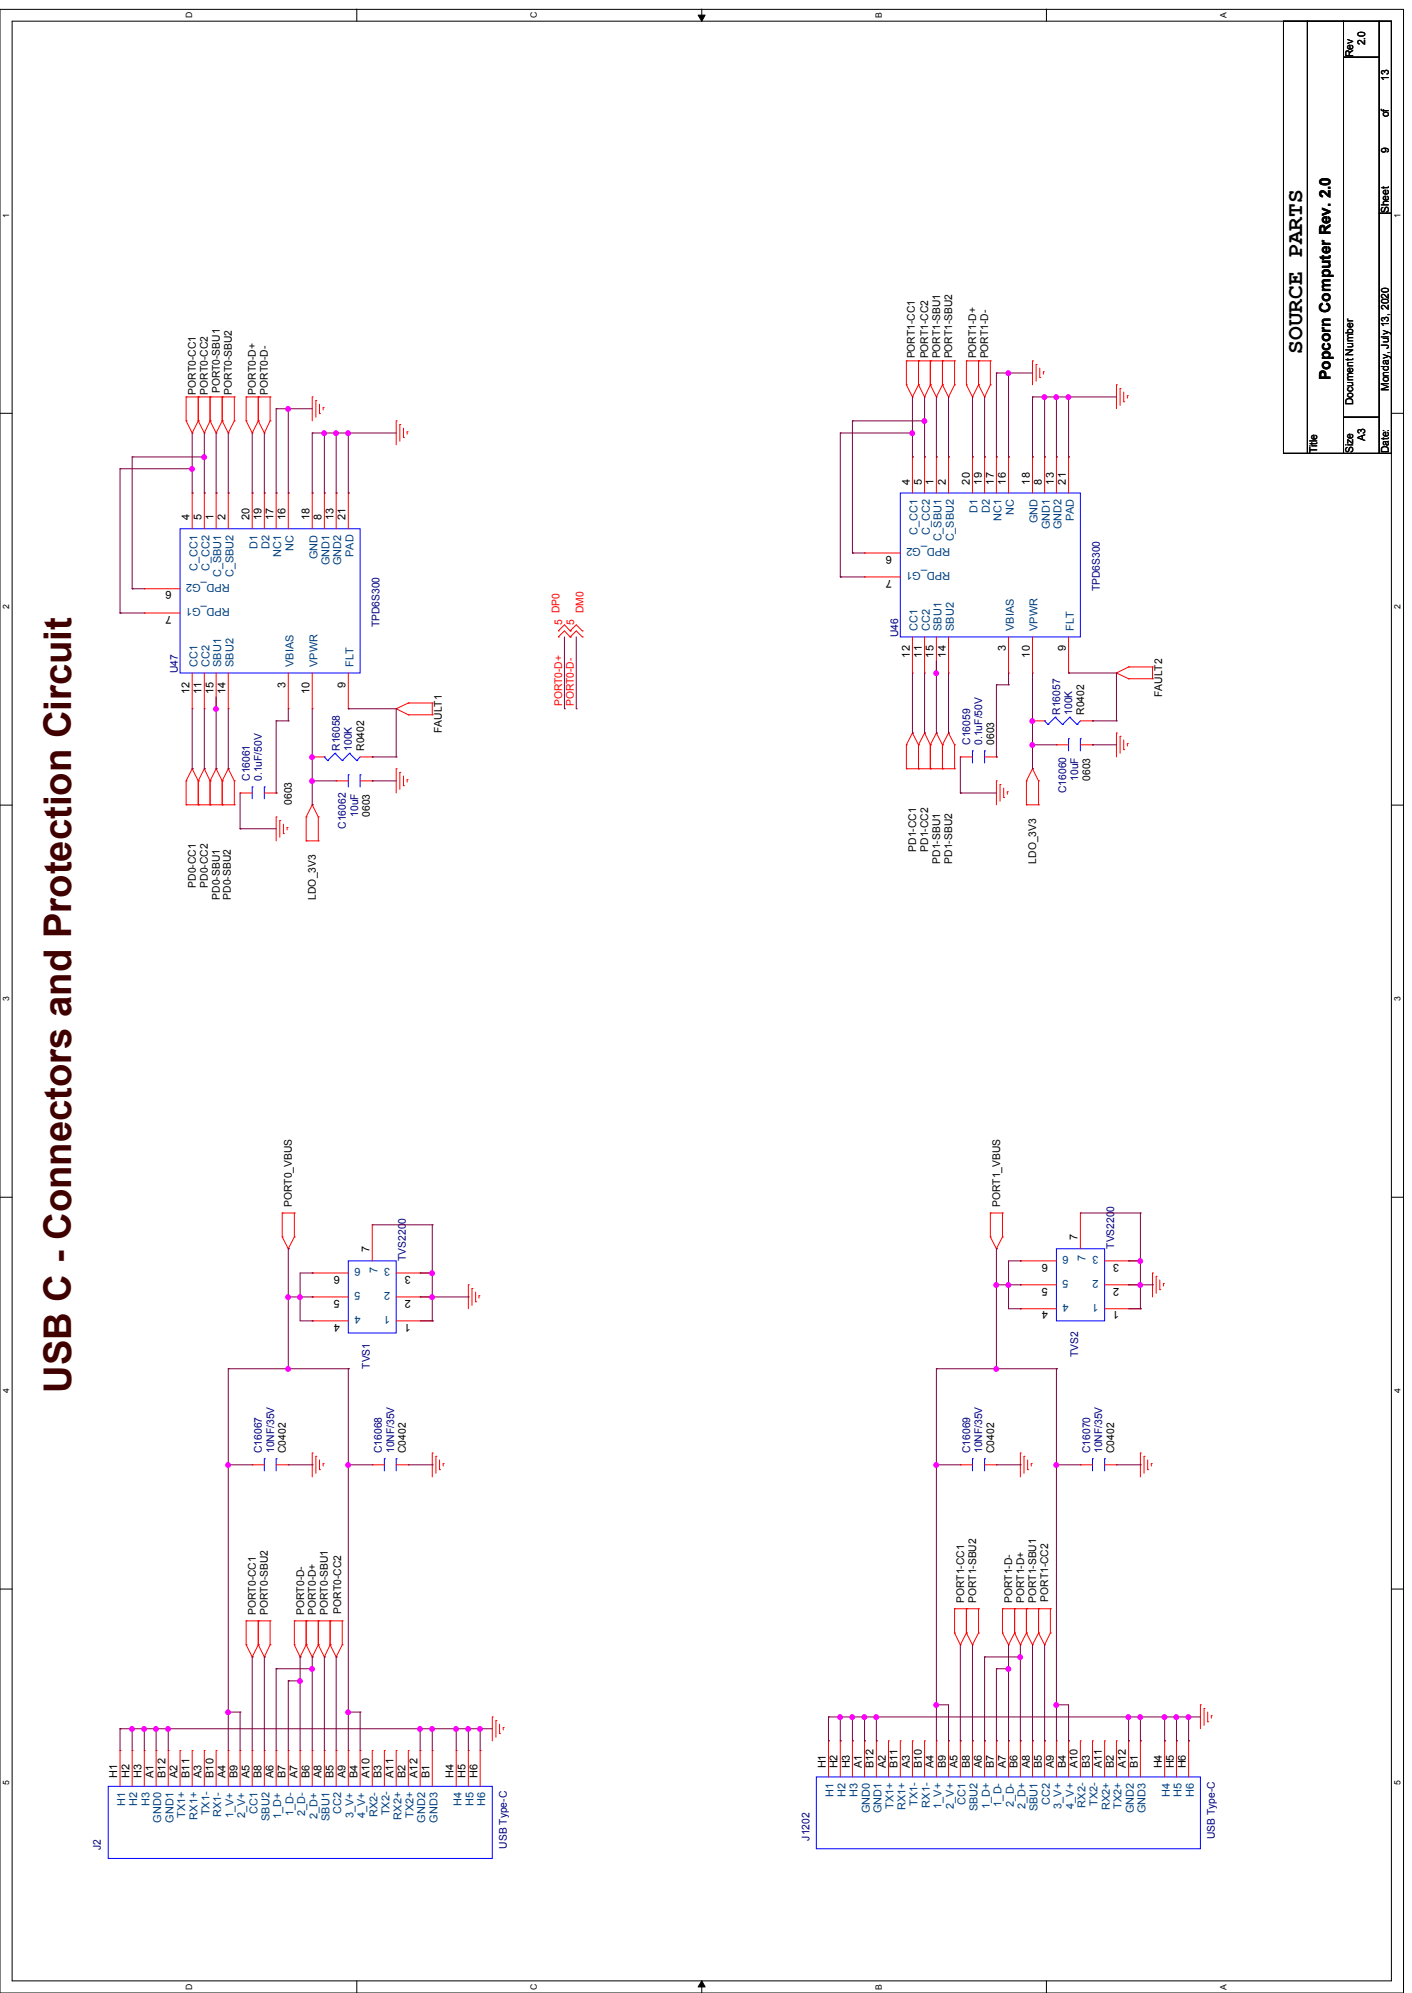
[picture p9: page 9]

Size Document Number Rev

USB C - Connectors and Protection Circuit

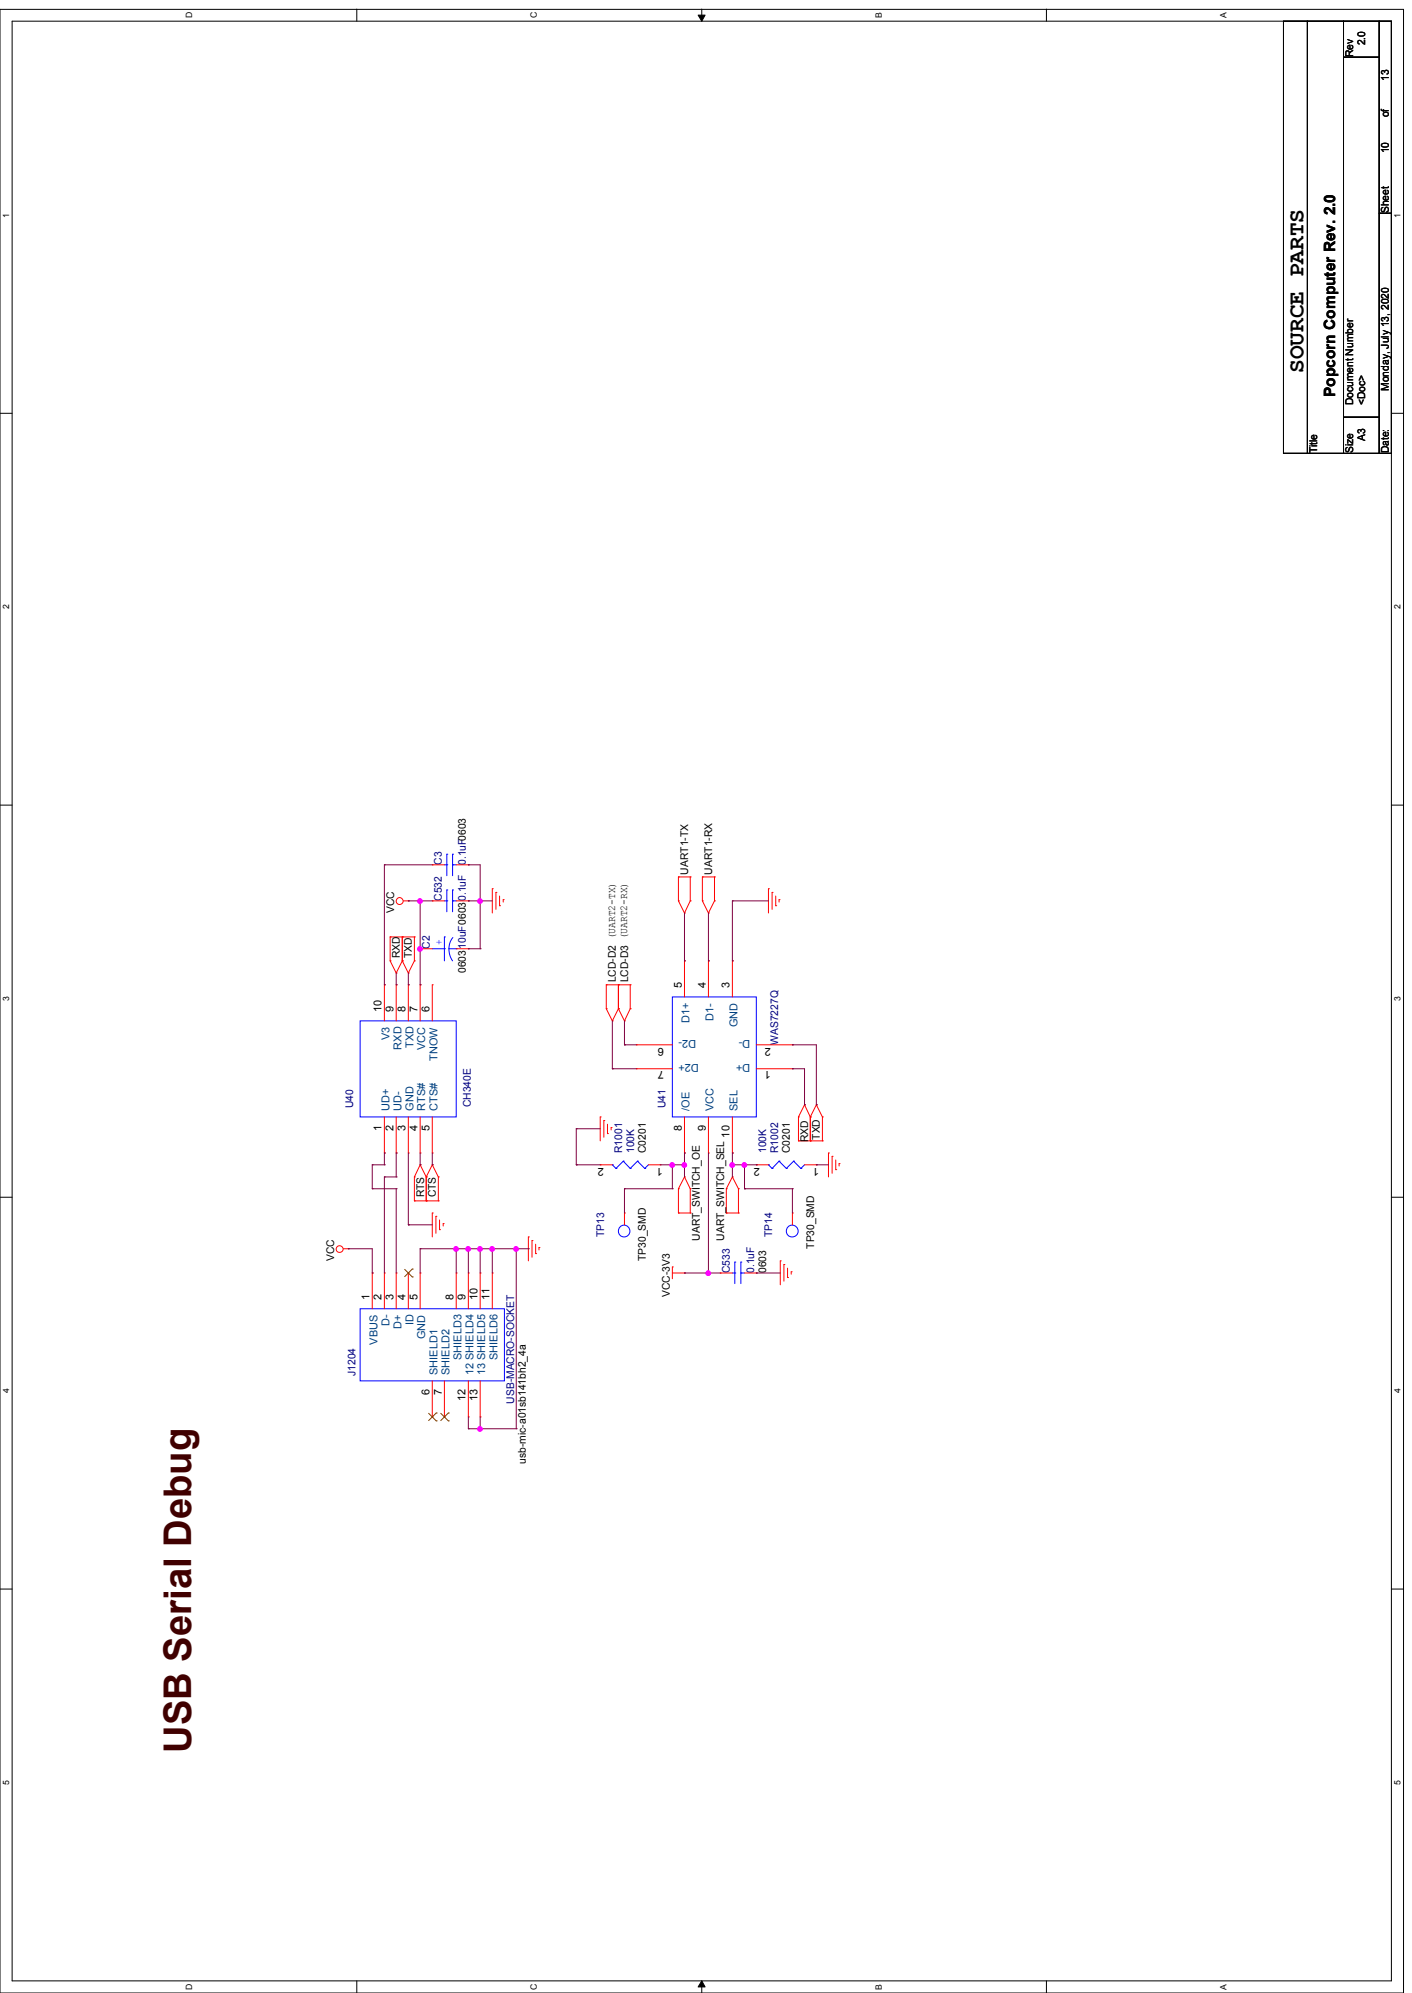
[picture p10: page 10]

Size Document Number Rev

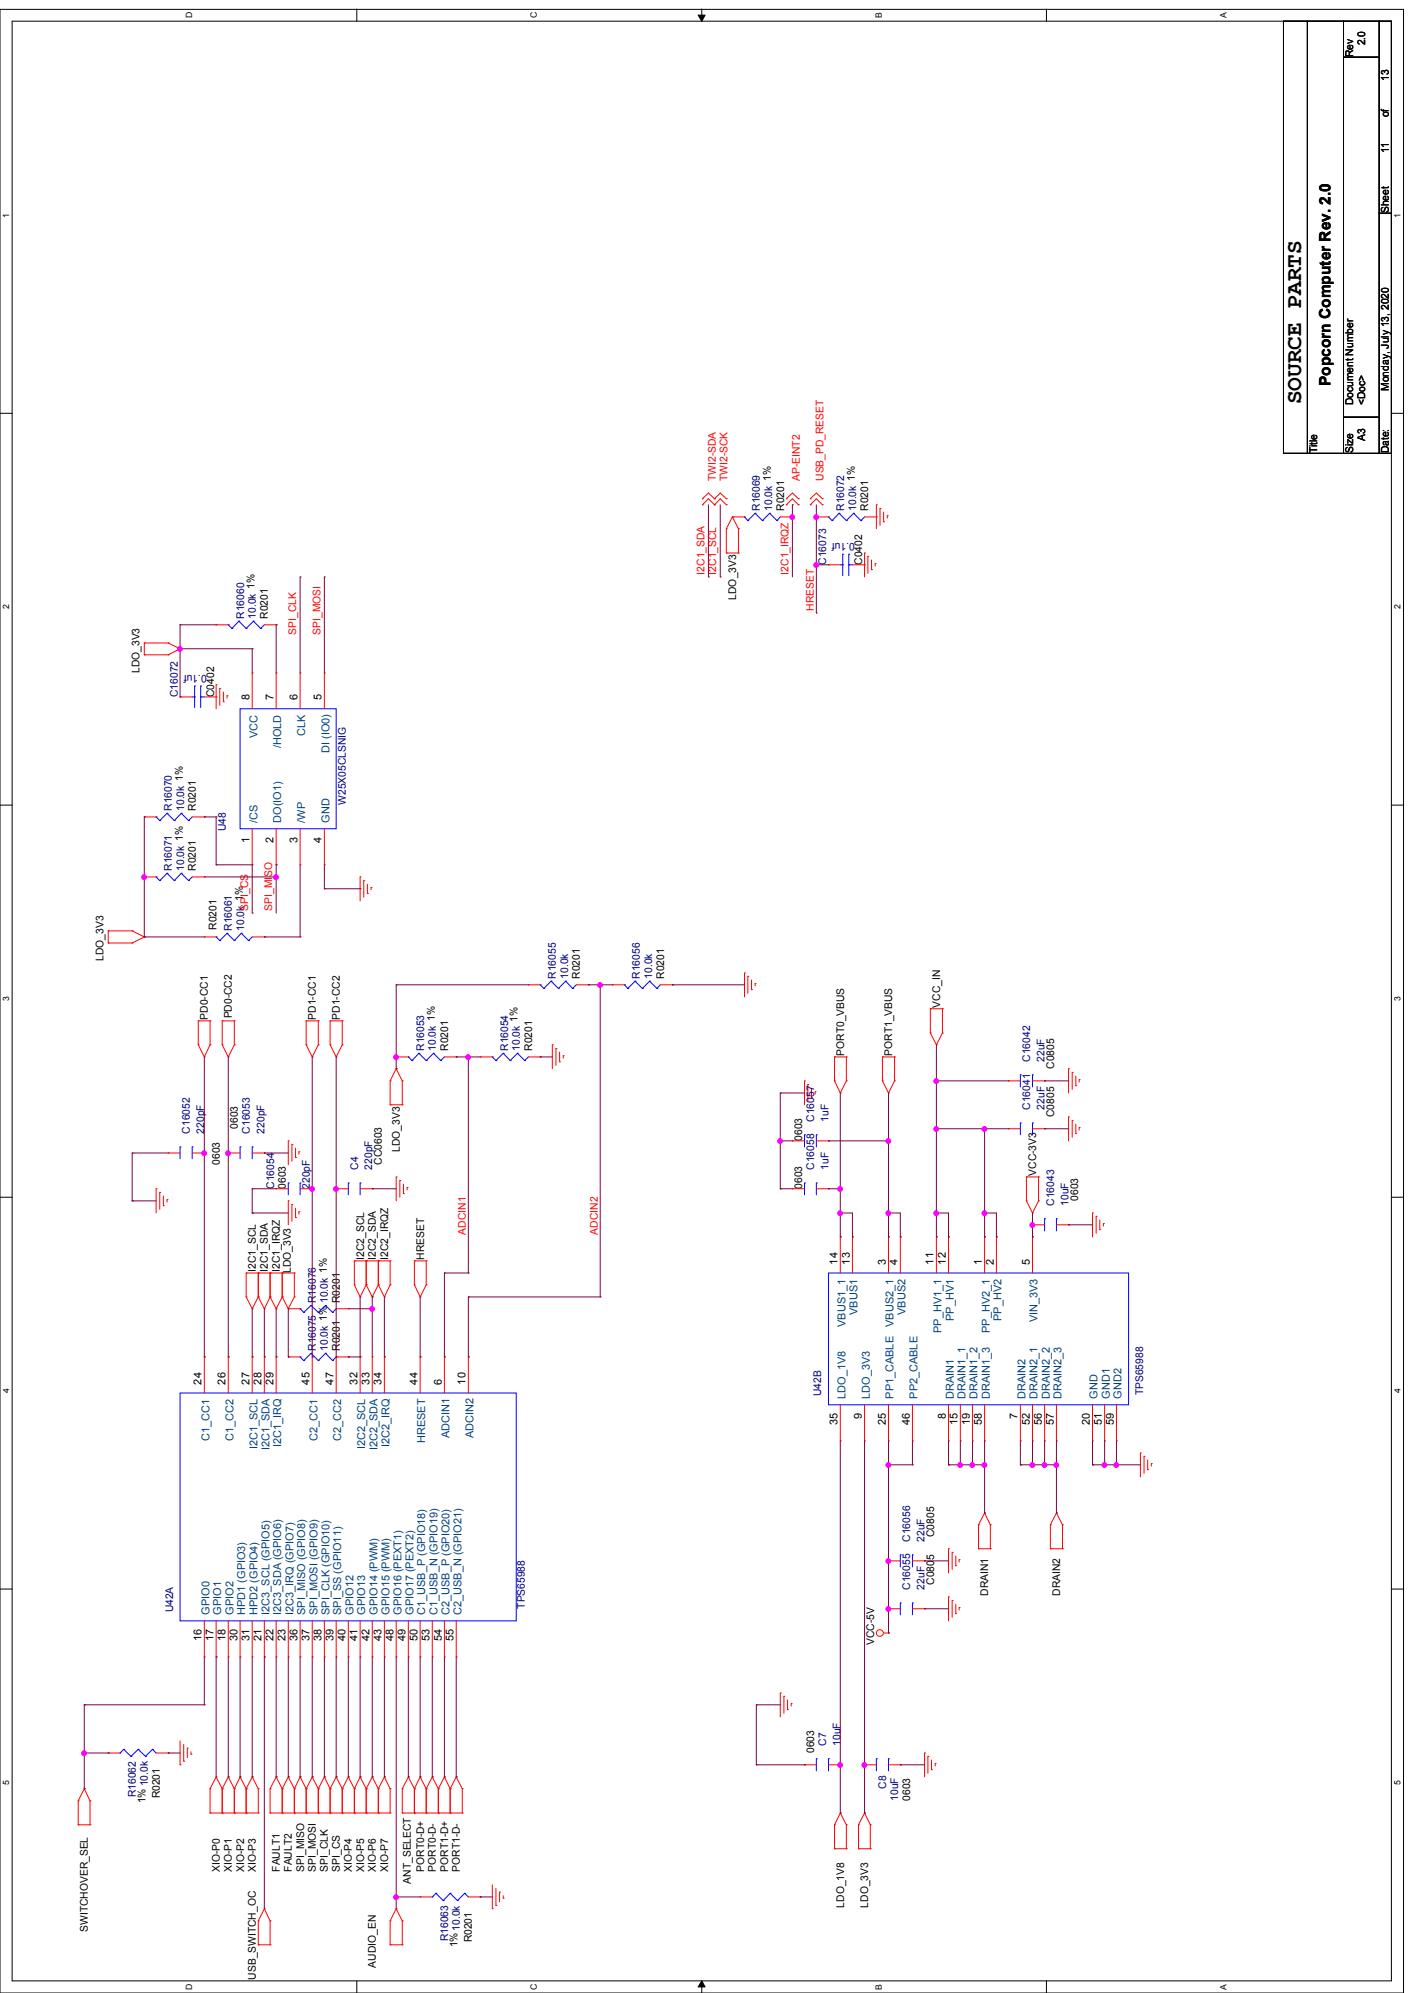
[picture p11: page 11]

Size Document Number Rev

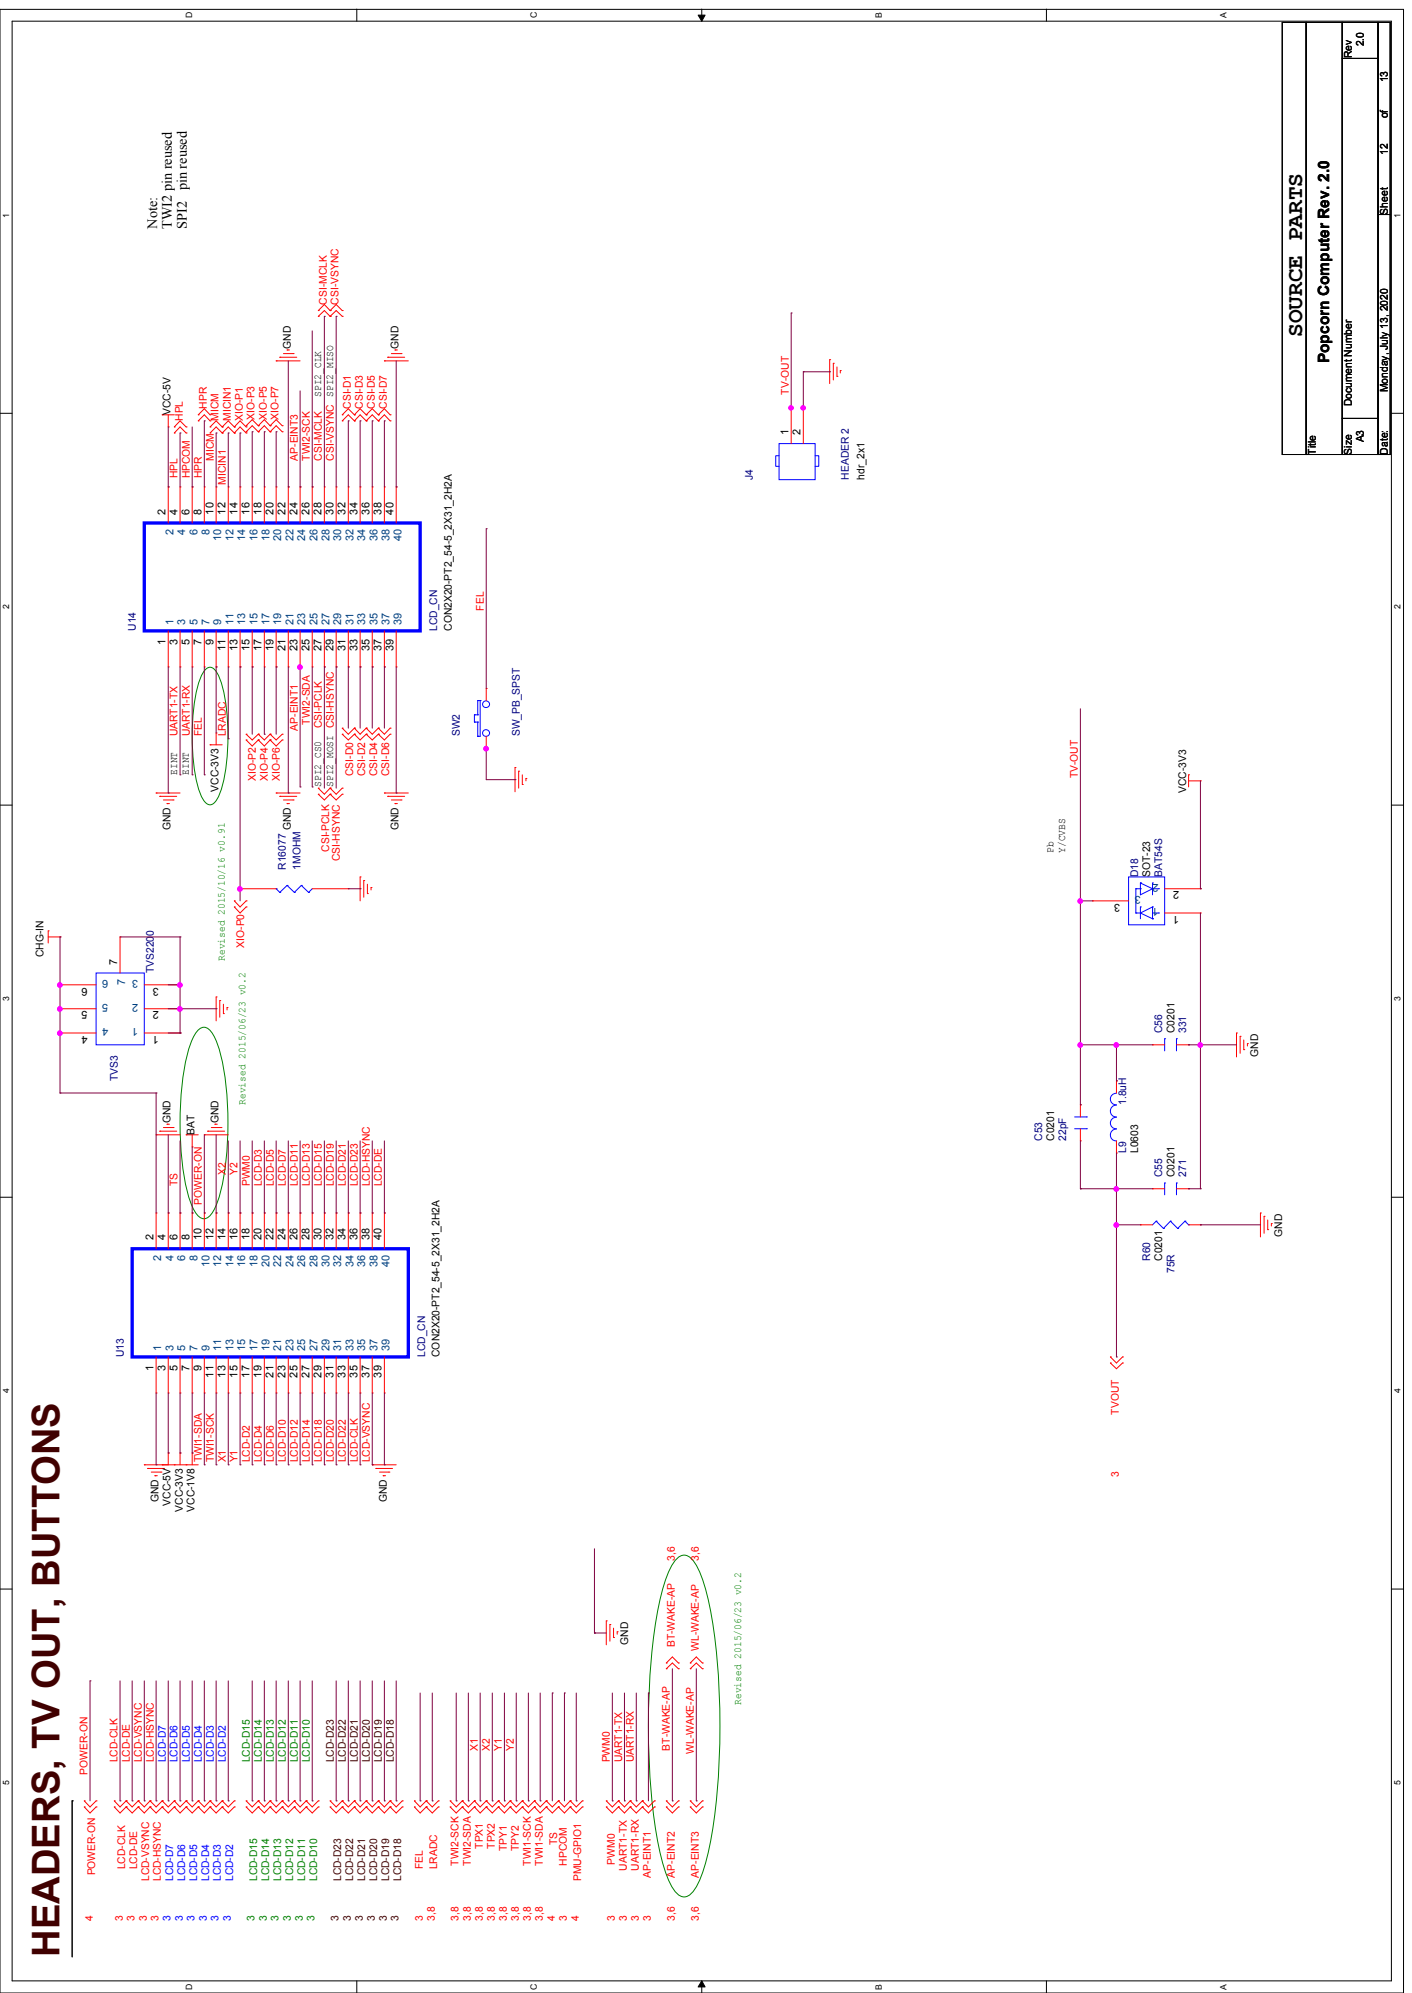
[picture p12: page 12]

Size Document Number Rev

HEADERS, TV OUT, BUTTONS


Size Document Number Rev

VCC-IO-WIFI

VBAT-EXT VCC-WIFI

VCC-IO-WIFI VCC-3V3

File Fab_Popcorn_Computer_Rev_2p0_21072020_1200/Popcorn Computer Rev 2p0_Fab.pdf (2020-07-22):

* DIELECTRIC - FR-4; FAB LAYER

DRILL CHART: TOP to BOTTOM
ALL UNITS ARE IN MILLIMETERS

FIGURE | SIZE | TOLERANCE | PLATED | QTY

0.2032 | +0.0508/-0.0508 | PLATED | 757
0.254 | +0.0762/-0.0762 | PLATED | 17
0.3048 | +0.0762/-0.0762 | PLATED | 10
0.7 | +0.0759/-0.0759 | PLATED | 2
1.0 | +0.0762/-0.0762 | PLATED | 80
1.0668 | +0.0762/-0.0762 | PLATED | 2
3.2 | +0.0759/-0.0759 | PLATED | 1
0.5999 | +0.0511/-0.0511 | NON-PLATED | 2
1.524x0.7112 | +0.0762/-0.0762 | PLATED | 4
1.5499x0.4501 | +0.0759/-0.0759 | PLATED | 2
1.3716x0.6604 | +0.0508/-0.0508 | NON-PLATED | 4
1.7272x0.762 | +0.0508/-0.0508 | NON-PLATED | 4

* SURFACE - AIR 0 MIL
L1: TOP CONDUCTOR - COPPER 1 Oz
* DIELECTRIC - FR-4

L2: GND-2 CONDUCTOR - COPPER 1/2 Oz

DESIGN CROSS SECTION CHART ___________________________ ¹.6mm ¹⁰% +

L3: SIG-3 CONDUCTOR - COPPER 1/2 Oz

Layers | Single Ended | Differential | Differential

Trace Width (Mils) | Impedance (Ohms) | Trace Width (Mils) | Trace Spacing (Mils) | Impedance (Ohms) | Trace Width (Mils) | Trace Spacing (Mils) | Impedance (Ohms)

L4: PWR-4 CONDUCTOR - COPPER 1/2 Oz

L5: GND-5 CONDUCTOR - COPPER 1/2 Oz

L8_Bot | 4.5 | 50 | 4 | 8.5 | 100

L6: SIG-6 CONDUCTOR - COPPER 1/2 Oz

L1_Top L8_Bot | 19(CPW) | 50

L7: PWR-7 CONDUCTOR - COPPER 1/2 Oz

L8: BOTTOM CONDUCTOR - COPPER 1 Oz

TOTAL THICKNESS 62.6 MIL

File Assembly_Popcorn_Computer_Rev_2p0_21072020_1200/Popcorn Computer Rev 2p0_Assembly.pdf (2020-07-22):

# L9003 C¹⁶⁰⁴⁰ U46

# U9012 C¹⁶⁰³⁹ R16039R¹⁶⁰³⁸


# C16060C¹⁶⁰⁵⁹

# R16072 R¹⁶⁰⁶⁴ R¹⁶⁰⁶⁵


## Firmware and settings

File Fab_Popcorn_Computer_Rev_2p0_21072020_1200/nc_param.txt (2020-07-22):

INTEGER-PLACES         2
DECIMAL-PLACES         5
X-OFFSET               0.000000
Y-OFFSET               0.000000
FEEDRATE               1
COORDINATES            ABSOLUTE
OUTPUT-UNITS           METRIC
TOOL-ORDER             INCREASING
REPEAT-CODES           YES
SUPPRESS-LEAD-ZEROES   NO
SUPPRESS-TRAIL-ZEROES  NO
SUPPRESS-EQUAL         NO
TOOL-SELECT            YES
OPTIMIZE_DRILLING      NO
ENHANCED_EXCELLON      NO
HEADER                 none
LEADER                 12
CODE                   ASCII
SEPARATE               NO
SEPARATE-ROUTING       NO
DRILLING               LAYER-PAIR
BACKDRILL              NO
CAVITY                 NO

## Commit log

2020-07-14 Add untested Original Popcorn Rev 2.0 design files
    [POPCORN_COMPUTER_REV_2P0_RELEASE.DSN, POPCORN_COMPUTER_REV_2P0_RELEASE_BOM.xlsx, art_param.txt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]
2020-07-15 update release to include impedance information for bottom layer (8) in fab drawing
    [art_param.txt, nc_param.txt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]
2020-07-22 previous release had trace width issues for factory impedance calculation, we modified the RF taces to 19mils from 13.5mils; we also increased the number of vias on a number of power traces and plane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
    [POPCORN_COMPUTER_REV_2P0_RELEASE.DSN, art_param.txt, nc_param.txt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]
